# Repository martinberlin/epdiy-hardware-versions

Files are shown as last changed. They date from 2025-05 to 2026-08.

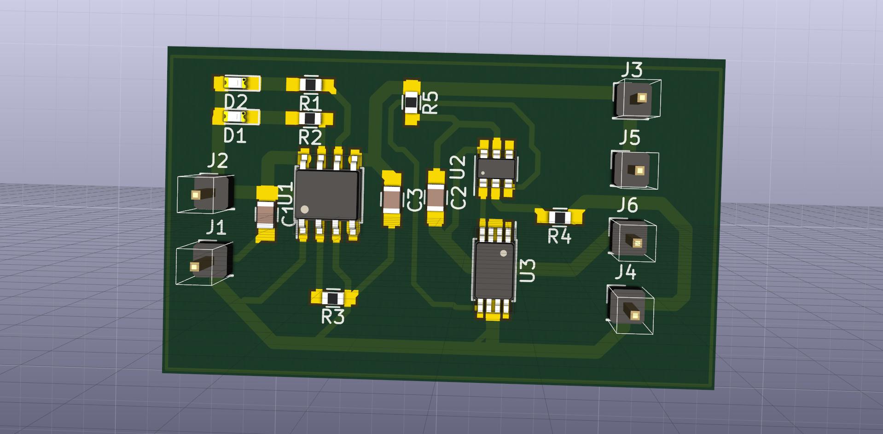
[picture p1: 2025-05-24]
versions/v7-raw-34/tp4056/out/charger_stepup2.jpg

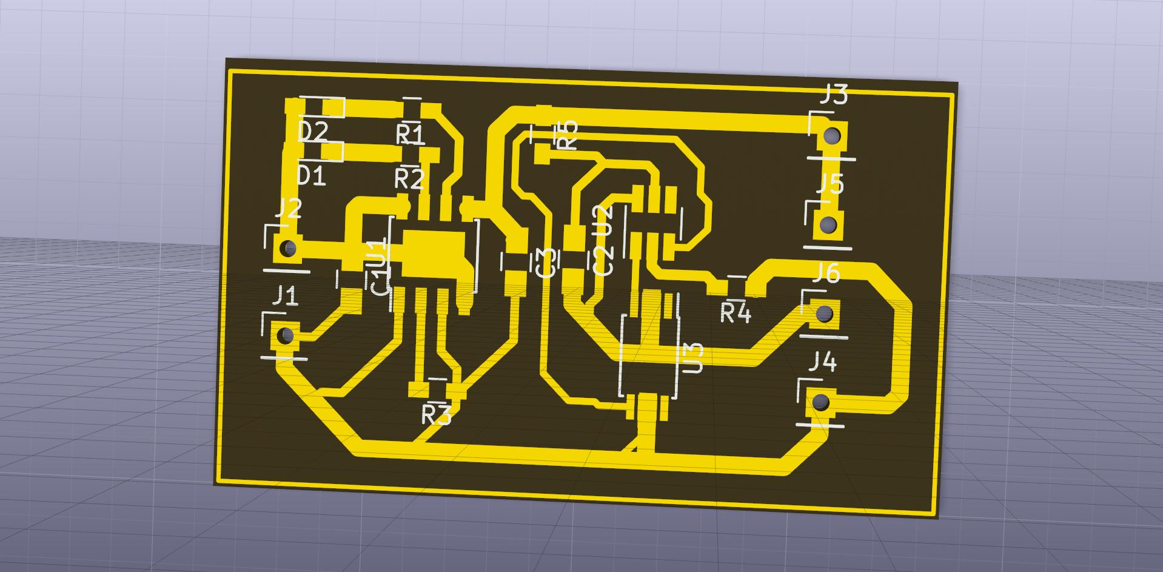
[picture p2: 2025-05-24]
versions/v7-raw-34/tp4056/out/charger_stepup1.jpg

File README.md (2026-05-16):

# EPDiy Hardware 

Design files for [EPDiy](https://github.com/vroland/epdiy) controllers, controller variants, display adaptors, and other related hardware.  
See [vroland.github.io/epdiy-hardware/](https://vroland.github.io/epdiy-hardware/) for available hardware.

## What is EPDiy?

Please refer to the [main project repository](https://github.com/vroland/epdiy) for more information.

## Cloning

Make sure to clone recursively, to get hardware library submodules:
```
git clone git@github.com:vroland/epdiy-hardware.git --recursive
# or with http
git clone https://github.com/vroland/epdiy-hardware.git --recursive
```

## Contributing Hardware

Contributions in the form of adapter boards, utilities or epdiy variants are always welcome!
Please submit a PR and make sure your KiCAD project is in the right format, so our automation can build 
the manufacturing files and overview page:

* For every board, the KiCAD project should be given a unique name, and have the same name as the containing folder. 
  Example: `epdiy-v7/epdiy-v7.{kicad_pro,kicad_pcb,kicad_sch}`. 
  An existing KiCAD project can be renamed by selecting `File -> Save As` in the main KiCAD window and saving it to a folder with the new name.
* Unless you *explicitly* specify otherwise, your contribution will be licensed under the Creative Commons Attribution-ShareAlike 4.0 International License.
  Feel free to mention in the README in your project folder how you want to be attributed.
  Please indicate in the PR if you intend to use a different license.
* Each board needs a README.md in it's project folder, which will also appear as description in the presentation page.
  Refer to `epdiy-v7/README.md` for an example.
* If it's a helper or an adapter board, place it in the appropriate `helpers` or `adapters` folder.
* Delete the manufacturing files and keep only the sources.
  Since we generate those automatically, having potentially outdated ones in the repo will be confusing. 
* Add your board to the `BOARDS` list in the root `Makefile`.
  This enables the continuous integration to build the manufacturing files for your board.

## Available Hardware

The full list of available hardware is available at [vroland.github.io/epdiy-hardware/](https://vroland.github.io/epdiy-hardware/).
For each board, we provide:

- Gerber files
- Bill of Materials (BoM)
- Pick & Place Positioning file
- PDF Schematic
- 3D model of the board for use in CAD

## Related repositories

- [Check FastJsonDL](https://github.com/martinberlin/FastJsonDL) a JSON domain language to draw GFX on displays that could be sent from a webservice or from an AI agent.
- [vroland/epdiy](https://github.com/vroland/epdiy)

## Licensing

Unless otherwise specified, the hardware sources provided are licensed under the terms of the Creative Commons Attribution-ShareAlike 4.0 International License.
<a rel="license" href="https://creativecommons.org/licenses/by-sa/4.0/">Creative Commons Attribution-ShareAlike 4.0 International License </a>

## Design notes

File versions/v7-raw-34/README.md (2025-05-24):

### Epdiy V7 RAW

The V7 controller iteration is based on the ESP32S3. Highlights of the new board include:

- Much faster updates thanks to the ESP32S3 SOC and the LCD peripheral
- Front light support for Kindle / Kaleido 
- LiPo charging

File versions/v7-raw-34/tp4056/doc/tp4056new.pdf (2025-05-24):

Модуль основан на чипе TP4056 (https://dlnmh9ip6v2uc.cloudfront.net/datasheets/Prototyping/TP4056.pdf) — контроллере зарядки Li-ion аккумуляторов со встроенным термодатчиком от NanJing Top Power ASIC Corp, это завершенное изделие с линейным зарядом по принципу постоянное напряжение/постоянный ток для одноэлементных литий-ионных аккумуляторов. Чип от компании из Нанкина, провинция Цзянсу, Китай. Специализация — системы питания игрушек, телефонов, LCD, LCM. Основана в 2003 году.
Контроллер выполнен в корпусе SOP-8, имет на нижней поверхности металлический теплосьемник не соединенный с контактами, позволяет заряжать аккумулятор током до 1000 ма (зависит от токозадающего резистора). Требует минимум навесных компонентов.
По сути это более навороченная модификация их же чипа TP4054, у которого в свою очередь куча аналогов (MCP73831, LTC4054, TB4054, TP4054, SGM4054, ACE4054, LP4054, U4054, BL4054, WPM4054, IT4504, Y1880, PT6102, PT6181, VS6102, HX6001, LC6000, LN5060, CX9058, EC49016, CYT5026, Q7051). Кто тут кому аналог, судить не берусь.

Расположение выводов:

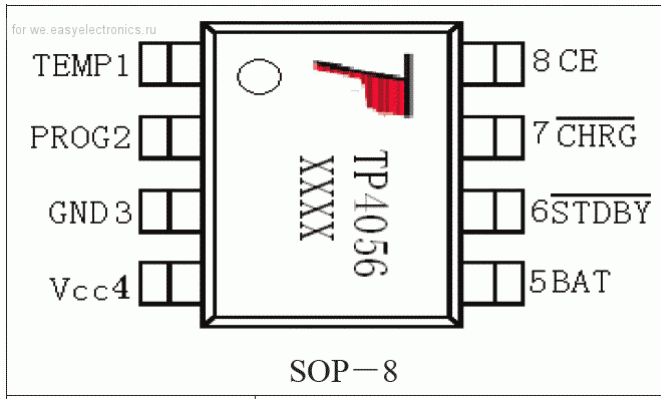
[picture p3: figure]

Описание выводов:
1. TEMP — подключение датчика температуры, встроенного в литий-ионную батарею. Если на выводе напряжение будет ниже 45% или выше 80% от напряжения питания, то зарядка приостановится. Контроль температуры отключается замыканием входа на общий провод.
2. PROG — Программирование тока зарядки (1.2к — 10к);
Постоянный ток зарядки и контроль напряжения зарядки выбираются сопротивлением резистора, между этим пином и GND;
Для всех режимов зарядки, зарядный ток может быть выведен из формулы:

3. GND — Общий;
4. Vcc — Напряжение питания, если ток потребления (ток зарядки батареи) становится ниже 30mA, контроллер уходит в спячку, потребляя от контакта BAT ~ 2mkA;
5. BAT — Подключение аккумуляторной батареи (ICR, IMR);
6. STDBY — Индикация окончания заряда (выход ОК, n-p-n), при слишком низком напряжении питания, или напряжении на входе ТЕМР не в диаппазоне — разомкнут; При подключенной батарее, в течении зарядки — разомкнут, по окончании — замкнут;
При неподключенной батарее замкнут;
7. CHRG — Индикация зарядки (выход ОК, n-p-n), при слишком низком напряжении питания, или напряжении на входе ТЕМР не в диаппазоне — разомкнут;
При подключенной батарее, в течении зарядки — замкнут, по окончании — разомкнут;
При неподключенной батарее, кратковременно включается с периодом 1-4 сек;
8. CE — Управление зарядкой. При подаче высокого уровня микросхема находится в рабочем режиме, при низком уровне контроллер в состоянии сна. Вход TTL и CMOS совместим;

Процесс зарядки состоит из нескольких этапов:
1. Контроль напряжения подключенного аккумулятора (постоянно);
2. Зарядка током 1/10 от запрограммированного резистором Rprog (100мА при Rprog = 1.2к) до уровня 2.9 В (если требуется);
3. Зарядка максимальным током (1000мА при Rprog = 1.2к);
4. При достижении на батарее 4.2 В идет стабилизация напряжения на уровне 4.2В. Ток падает по мере зарядки;
5. При достижении тока 1/10 от запрограммированного резистором Rprog (100мА при Rprog = 1.2к) зарядное устройство отключается. Переход к п. 1

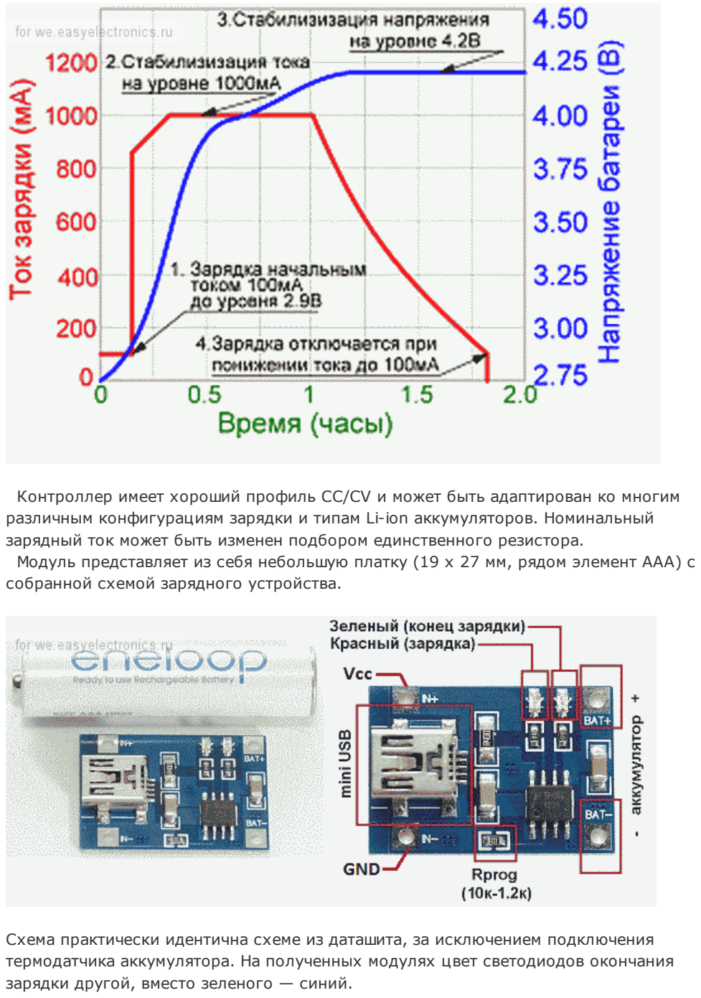
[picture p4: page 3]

Контроллер имеет хороший профиль CC/CV и может быть адаптирован ко многим различным конфигурациям зарядки и типам Li-ion аккумуляторов. Номинальный зарядный ток может быть изменен подбором единственного резистора.
Модуль представляет из себя небольшую платку (19 х 27 мм, рядом элемент ААА) с собранной схемой зарядного устройства.

Схема практически идентична схеме из даташита, за исключением подключения термодатчика аккумулятора. На полученных модулях цвет светодиодов окончания зарядки другой, вместо зеленого — синий.

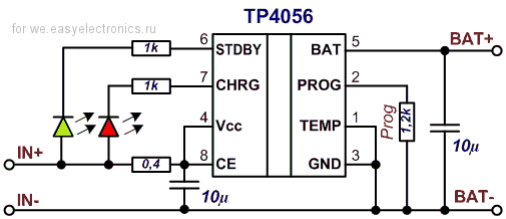
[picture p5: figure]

Можно (если понадобилось) вывести вход термодатчика отдельным проводком, напаявшись на лапку и отрезав ее от GND. Или же подняв лапку над платой и напаявшись. Если же хочется без паяния, надо просто заказать там же другой модуль:

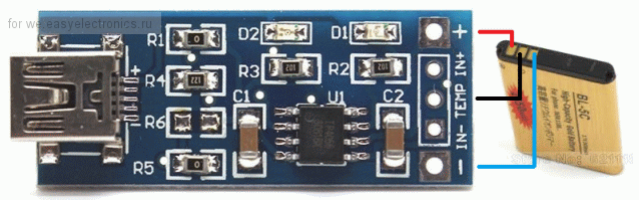
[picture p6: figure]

Отличие только в компоновке и габаритах (37x15мм).

Описание:
Напряжение питания +4,5...+8,0 вольт (более 5,5 В не рекомендуется, чип перегревается);
Разьем Mini-USB на плате, для питания от USB-порта компьютера или универсального блока питания;
Ток заряда 1,0 Ампер (1000 мА), легко программируется изменением значения резистора Rprog (от 1,2k до 10k (по даташиту, на самом деле до ~30k));
Важно: источник питания (USB порт, USB адаптер, или др.) должен обеспечивать ток заряда с некоторым запасом. Не все порты USB могут обеспечить ток более 500 мА; Напряжение окончания заряда аккумулятора: 4,2 вольта;
Светодиод индикации заряда;
Светодиод индикации окончания заряда;
Готовый модуль;
Миниатюрные размеры 19 х 27 мм;
Вес модуля 1,9 гр;

Тесты зарядки реальных аккумуляторов:

Заявленная емкость 3400mAh:

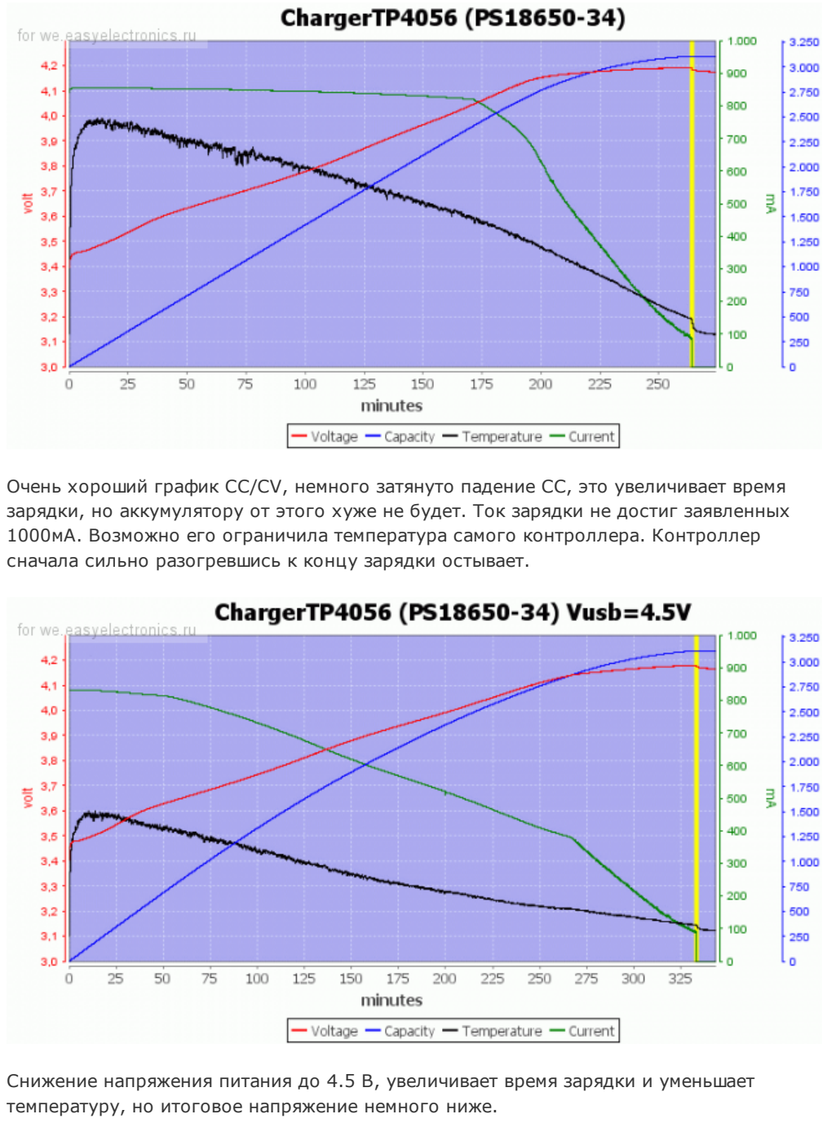
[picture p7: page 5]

Очень хороший график CC/CV, немного затянуто падение СС, это увеличивает время зарядки, но аккумулятору от этого хуже не будет. Ток зарядки не достиг заявленных 1000мА. Возможно его ограничила температура самого контроллера. Контроллер сначала сильно разогревшись к концу зарядки остывает.

Снижение напряжения питания до 4.5 В, увеличивает время зарядки и уменьшает температуру, но итоговое напряжение немного ниже.

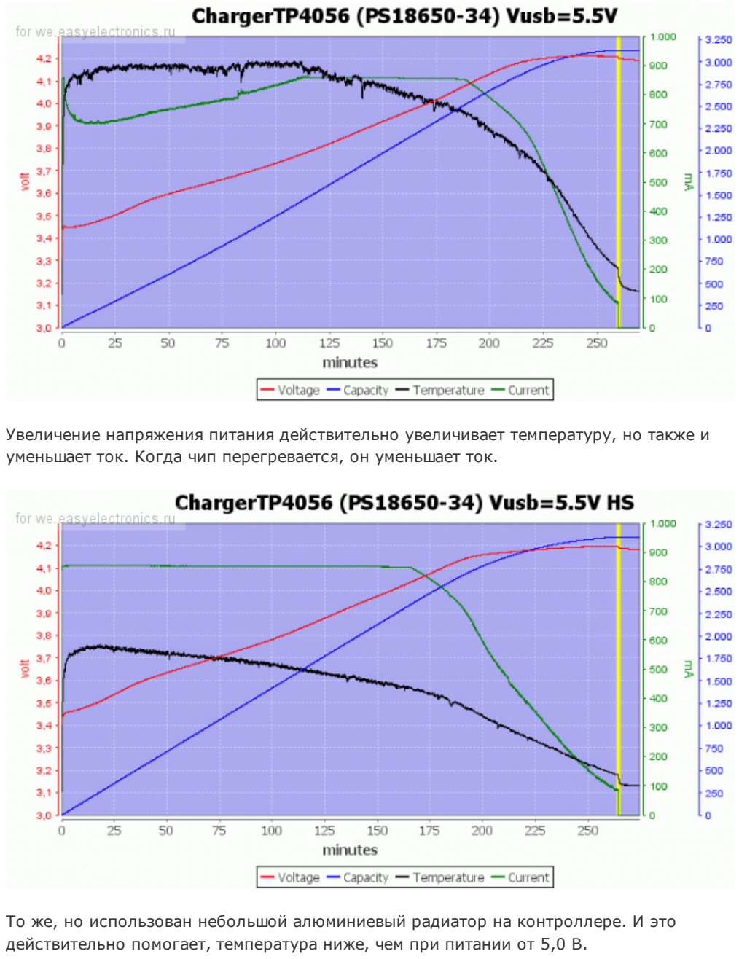
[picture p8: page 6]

Увеличение напряжения питания действительно увеличивает температуру, но также и уменьшает ток. Когда чип перегревается, он уменьшает ток.

То же, но использован небольшой алюминиевый радиатор на контроллере. И это действительно помогает, температура ниже, чем при питании от 5,0 В.

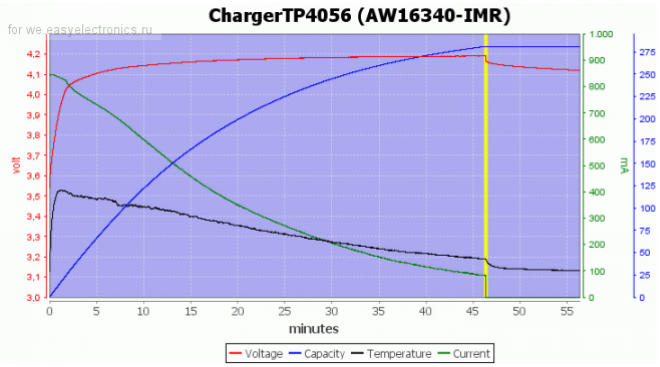
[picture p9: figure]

Старый 16340 IMR аккумулятор от видеокамеры также был заряжен успешно.

После окончания зарядки контроллер продолжает мониторинг напряжения аккумулятора. Ток, потребляемый схемой мониторинга 2-3 mkA. После падения напряжения до 4.0В, зарядка включается снова.
При отключении и подключении аккумулятора, зарядка включится только если напряжение аккумулятора ниже 4.0В.

Внимание!!! Контроллер имеет одну особенность, не описанную в даташите. Он не содержит схемы защиты от переполюсовки батареи. В этом случае контроллер гарантированно выходит из строя из-за превышения максимального тока и теплового пробоя. Но это только полбеды, контроллер пробивается накоротко, и на его выходе (батарее) появляется полное (!) входное напряжение.
Это особенно актуально для заряда пальчиковых аккумуляторов типа 18650. При установке очень легко ошибиться с полярностью.

Можно купить и модули с защитой:

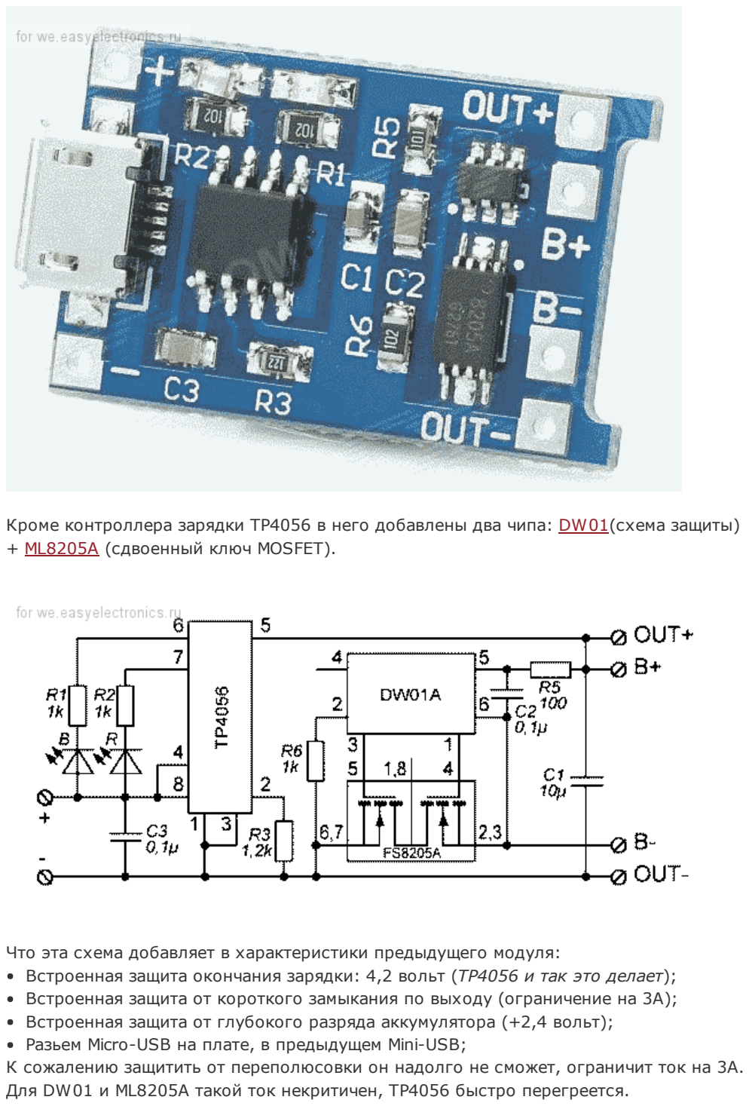
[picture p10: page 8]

Кроме контроллера зарядки ТP4056 в него добавлены два чипа: DW01(схема (https://cdn.sparkfun.com/assets/learn_tutorials/2/5/1/DW01-P_DataSheet_V10.pdf) защиты) + ML8205A (http://www.datasheet-pdf.com/datasheet-download.php?id=847699) (сдвоенный ключ MOSFET).

Что эта схема добавляет в характеристики предыдущего модуля:
Встроенная защита окончания зарядки: 4,2 вольт (ТP4056 и так это делает); Встроенная защита от короткого замыкания по выходу (ограничение на 3А); Встроенная защита от глубокого разряда аккумулятора (+2,4 вольт);
Разьем Micro-USB на плате, в предыдущем Mini-USB;
К сожалению защитить от переполюсовки он надолго не сможет, ограничит ток на 3А. Для DW01 и ML8205A такой ток некритичен, ТP4056 быстро перегреется.

Чего хотелось достичь?

Ранее я заказал и описАл простую платку (http://we.easyelectronics.ru/Shematech/platka-rasshireniya-tiny-rtc-i2c-modules.html) с DS1307Z и AT24C32 на борту.
Для резервного питания часов там заложен Li-ion аккумулятор LIR2032. Его подзарядка осуществляется постоянно, через резистор (1,8мкА), от питающего напряжения. Хотя упоминаний об этом в инете нет, меня убедили, что такая схема зарядки быстро убивает аккумулятор.
Данная зарядка бралась на замену резистору. Такая замена естественно дороже. Хотя если учесть цену данной платы (13,74 руб), плюсов будет больше.

Тестовая работа по подключению маломощного аккумулятора LIR2032 к зарядке на TP4056 была проведена здесь: (http://smokedprojects.blogspot.ru/2014/01/1-lithium-coin-cell-charger.html)

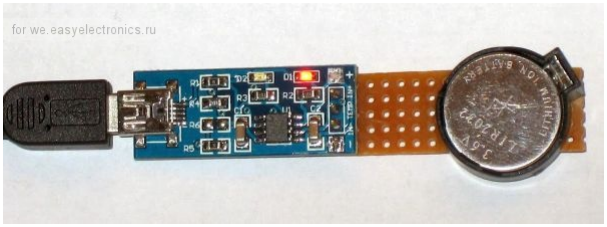
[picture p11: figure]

Автор изменил сопротивление токозадающего резистора с 1,2к на 33к, зарядный ток уменьшился до 45мА. По словам автора, зарядка разряженного аккумулятора занимает около часа.
Как это будет выглядеть в теории? Даташит на Li-MnO2
аккумуляторLIR2032 (http://www.astc.ru/data/delivery_list/content/eemb/pdf/LIR2032.pdf) рекомендует зарядку номинальным током 20мА и напряжением 4,2В. После падения тока до 4мА батарею можно считать полностью заряженной. Максимальный ток зарядки 35-45мА, в зависимости от производителя. Минимальное напряжение разряда аккумулятора до начала деградации ячейки 2,75В. Для аккумулятора гарантируется 500 циклов заряда/разряда с сохранением после них не менее 80% емкости.
В свою очередь контроллер Tp4056 не сможет обеспечить ток зарядки ниже 30мА, просто уйдет в сон. И ждать пока напряжение на аккумуляторе упадет до 2,75В тоже не будет, включит зарядку уже при падении до 4,0В. Таким образом он будет постоянно поддерживать аккумулятор на ~85-95% заряженным. Наверное это не оптимально для ячейки, но все же лучше, чем через резистор.

TP4056, (http://we.easyelectronics.ru/tag/TP4056/) Li-Ion (http://we.easyelectronics.ru/tag/Li-Ion/)

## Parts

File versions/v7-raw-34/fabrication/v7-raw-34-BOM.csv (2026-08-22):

Comment | Designator | Footprint | LCSC
4.7uF | C1,C4,C5,C7,C8,C11,C24,C26,C28,C31 | Capacitor_SMD:C_0805_2012Metric | C1779
1uF | C13,C14,C18 | Capacitor_SMD:C_0805_2012Metric | C28323
100nF | C15,C22,C23,C29,C30,C42 | Capacitor_SMD:C_0805_2012Metric | C49678
100uF | C17 | Capacitor_Tantalum_SMD:CP_EIA-3528-15_AVX-H | C16133
10uF | C2,C3,C9,C12,C16,C19,C32,C43 | Capacitor_SMD:C_0805_2012Metric | C15850
10nF | C20,C25 | Capacitor_SMD:C_0805_2012Metric | C1710
C_Polarized 100uF | C21 | Capacitor_Tantalum_SMD:CP_EIA-3528-21_Kemet-B | C129289
2.2uF | C27,C33 | Capacitor_SMD:C_0805_2012Metric | C49217
1uF/50V | C34,C36 | Capacitor_SMD:C_1206_3216Metric | C1848
1uF/25V | C35,C37,C38,C44 | Capacitor_SMD:C_0805_2012Metric | C28323
12 pF | C39,C40 | Capacitor_SMD:C_0603_1608Metric | C38523
22uF | C6,C10 | Capacitor_SMD:C_0805_2012Metric | C45783
MBR0540 | D1,D2,D3,D4,D5,D6,D7,D11 | Diode_SMD:D_SOD-123 | C21353
1N5817 | D10 | Diode_SMD:D_SOD-123 | C8598
1N4148WS | D12 | Diode_SMD:D_SOD-323 | C2128
LED GREEN | D8 | LED_SMD:LED_0805_2012Metric | C2297
LED RED | D9 | LED_SMD:LED_0805_2012Metric | C84256
USB_C_Receptacle_USB2.0 | J1,J4 | Connector_USB:USB_C_Receptacle_HRO_TYPE-C-31-M-12 | C165948
THD2528-11SD-GF | J11 | THD252811SDGF | C283232
S2B-PH-SM4-TB_LF__SN_ | J2 | footprint:S2BPHSM4TBLFSN | C295747
FH34SRJ-6S-0.5SH_99_ | J6 | footprint:C224194_6x1_FH34SRJ-6S-0.5SH50_HIR | C224194
4.7uH | L1 | Inductor_SMD:L_Taiyo-Yuden_NR-50xx_HandSoldering | C222947
2.2uH | L2 | Inductor_SMD:L_Taiyo-Yuden_NR-40xx_HandSoldering | C92959
22 uH | L3 | footprint:SWPA5040S282MT | C68434
AO3401A | Q1 | Package_TO_SOT_SMD:SOT-23 | C15127
MMBT3904 | Q3,Q4 | Package_TO_SOT_SMD:SOT-23 | C20526
10k | R1,R4,R6,R10,R11,R12,R14,R15 | Resistor_SMD:R_0603_1608Metric | C25804
25Ω | R13 | Resistor_SMD:R_0603_1608Metric | C308324
10 K | R17 | Resistor_SMD:R_0603_1608Metric | C25804
43k | R18 | Resistor_SMD:R_0603_1608Metric | C23172
1M | R19,R23 | Resistor_SMD:R_0603_1608Metric | C22935
5.1k | R2,R7 | Resistor_SMD:R_0603_1608Metric | C23186
52.3k | R20 | Resistor_SMD:R_0603_1608Metric | C23196
680k | R21 | Resistor_SMD:R_0603_1608Metric | C25822
150k | R22 | Resistor_SMD:R_0603_1608Metric | C22807
47.5k | R24 | Resistor_SMD:R_0603_1608Metric | C25819
47k | R26,R27,R28,R29 | Resistor_SMD:R_0603_1608Metric | C25819
2.4k | R3,R8 | Resistor_SMD:R_0603_1608Metric | C22940
100k | R30,R31 | Resistor_SMD:R_0603_1608Metric | C25803
0R | R5,R16 | Resistor_SMD:R_0603_1608Metric | C21189
3.8k | R9 | Resistor_SMD:R_0603_1608Metric | C103591
R_Pack04 | RN1 | footprint:RESN_F392JTCE_UNR_SD-pullup | C425297
10k/3380K | TH1 | Resistor_SMD:R_0603_1608Metric | C76589
RT9080-33GJ5 | U1 | Package_TO_SOT_SMD:TSOT-23-5 | C841192
ED060XC5 | U10 | epaper-breakout:X05A20H34G | C528053
TP4056 | U11 | epaper-breakout:TP4056_SOP-8-PP | C16581
PCF8563T | U2 | Package_SO:SOIC-8_3.9x4.9mm_P1.27mm | C7440
TPS651851RSLR | U3 | footprint:TPS651851RSLR | C139292
USBLC6-2P6 | U4 | Package_TO_SOT_SMD:SOT-666 | C2827693
XC6206PxxxMR | U5 | Package_TO_SOT_SMD:SOT-23-3 | C5446
RY3730 | U6 | footprint:SOT-23-6_RY3730_Led_PWM | C370887
ESP32-S3-WROOM-1 | U8 | Espressif:ESP32-S3-WROOM-1 | C2913202
CH340C | U9 | Package_SO:SOIC-16_3.9x9.9mm_P1.27mm | C84681
Crystal_Small | Y1 | footprint:Q13FC1350000400-Crystal | C32346
SM04B-SRSS-TB_LFSN_ | J12 | QWIIC_SM04B-SRSS-TB_LFSN_ | C160404

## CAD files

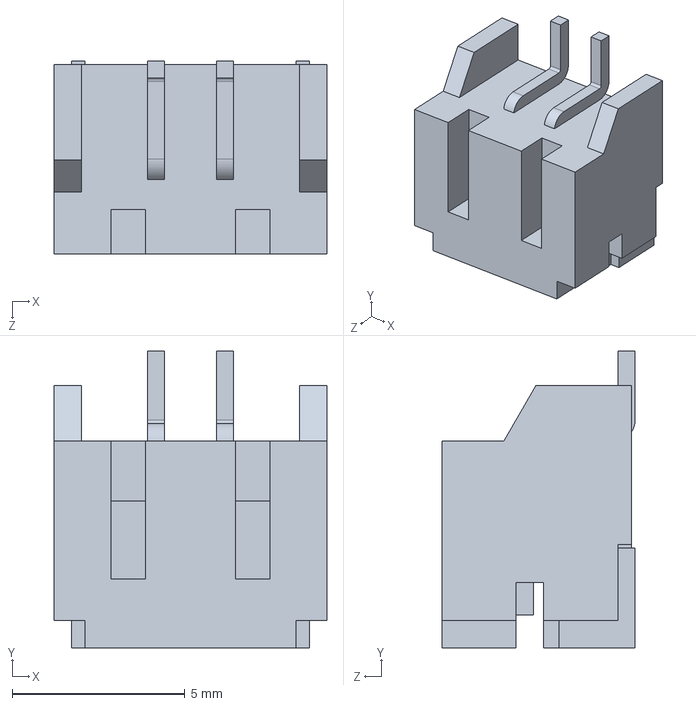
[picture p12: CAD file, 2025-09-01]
versions/v7-raw-34/3dmodels/S2B-PH-SM4-TB_LF__SN_.stp
7.90 x 8.60 x 5.60 mm

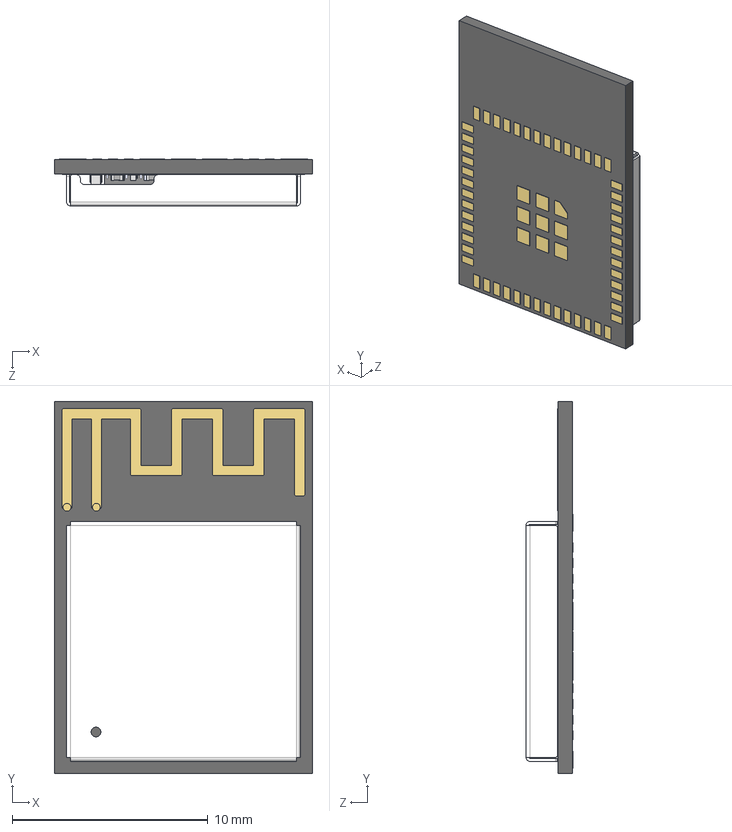
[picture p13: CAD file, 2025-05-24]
versions/v7-raw-34/kicad-libraries/3d/ESP32-MINI-1.STEP
13.2 x 19.0 x 2.40 mm
DFN1006.STEP^DFN1006.STEP_Submodel-SOD882_part_DesignRootModel_PCB_ESP32-MINI-1_V1(2)_PCB_ESP32-MINI-1_V1
trace_1^Submodel-MINI-ANT-TYPED_2110587435_part_DesignRootModel_PCB_ESP32-MINI-1_V1(2)_PCB_ESP32-MINI-1_V1
C0402_20210301.STEP^C0402_20210301.STEP_Submodel-C0402_part_DesignRootModel_PCB_ESP32-MINI-1_V1(2)_PCB_ESP32-MINI-1_V1
R0201_20210301.STEP^R0201_20210301.STEP_Submodel-R0201_part_DesignRootModel_PCB_ESP32-MINI-1_V1(2)_PCB_ESP32-MINI-1_V1 x 3
C0201_20210301.STEP^C0201_20210301.STEP_Submodel-C0201_part_DesignRootModel_PCB_ESP32-MINI-1_V1(2)_PCB_ESP32-MINI-1_V1 x 15
L0201_20210301.STEP^L0201_20210301.STEP_Submodel-L0201_part_DesignRootModel_PCB_ESP32-MINI-1_V1(2)_PCB_ESP32-MINI-1_V1 x 2
XTAL3225_20210301.STEP^XTAL3225_20210301.STEP_Submodel-XTAL3225_part_DesignRootModel_PCB_ESP32-MINI-1_V1(2)_PCB_ESP32-MINI-1_V1
ESP32_5x5_20210301.STEP^ESP32_5x5_20210301.STEP_Submodel-QFN48EB_0P35_5_part_DesignRootModel_PCB_ESP32-MINI-1_V1(2)_PCB_ESP32-MINI-1_V1
uid__4^DesignRootModel_PCB_ESP32-MINI-1_V1(2)_PCB_ESP32-MINI-1_V1
uid__4-1^DesignRootModel_PCB_ESP32-MINI-1_V1(2)_PCB_ESP32-MINI-1_V1
uid__4-2^DesignRootModel_PCB_ESP32-MINI-1_V1(2)_PCB_ESP32-MINI-1_V1
uid__4-3^DesignRootModel_PCB_ESP32-MINI-1_V1(2)_PCB_ESP32-MINI-1_V1
uid__4-4^DesignRootModel_PCB_ESP32-MINI-1_V1(2)_PCB_ESP32-MINI-1_V1
uid__4-5^DesignRootModel_PCB_ESP32-MINI-1_V1(2)_PCB_ESP32-MINI-1_V1
uid__4-6^DesignRootModel_PCB_ESP32-MINI-1_V1(2)_PCB_ESP32-MINI-1_V1
uid__4-7^DesignRootModel_PCB_ESP32-MINI-1_V1(2)_PCB_ESP32-MINI-1_V1
uid__4-8^DesignRootModel_PCB_ESP32-MINI-1_V1(2)_PCB_ESP32-MINI-1_V1
uid__4-9^DesignRootModel_PCB_ESP32-MINI-1_V1(2)_PCB_ESP32-MINI-1_V1
uid__4-10^DesignRootModel_PCB_ESP32-MINI-1_V1(2)_PCB_ESP32-MINI-1_V1
uid__4-11^DesignRootModel_PCB_ESP32-MINI-1_V1(2)_PCB_ESP32-MINI-1_V1
uid__4-12^DesignRootModel_PCB_ESP32-MINI-1_V1(2)_PCB_ESP32-MINI-1_V1
uid__4-18^DesignRootModel_PCB_ESP32-MINI-1_V1(2)_PCB_ESP32-MINI-1_V1
uid__4-19^DesignRootModel_PCB_ESP32-MINI-1_V1(2)_PCB_ESP32-MINI-1_V1
uid__4-31^DesignRootModel_PCB_ESP32-MINI-1_V1(2)_PCB_ESP32-MINI-1_V1
uid__4-32^DesignRootModel_PCB_ESP32-MINI-1_V1(2)_PCB_ESP32-MINI-1_V1
uid__4-44^DesignRootModel_PCB_ESP32-MINI-1_V1(2)_PCB_ESP32-MINI-1_V1
uid__4-45^DesignRootModel_PCB_ESP32-MINI-1_V1(2)_PCB_ESP32-MINI-1_V1
uid__4-55^DesignRootModel_PCB_ESP32-MINI-1_V1(2)_PCB_ESP32-MINI-1_V1
uid__4-56^DesignRootModel_PCB_ESP32-MINI-1_V1(2)_PCB_ESP32-MINI-1_V1
uid__4-61^DesignRootModel_PCB_ESP32-MINI-1_V1(2)_PCB_ESP32-MINI-1_V1
uid__4-62^DesignRootModel_PCB_ESP32-MINI-1_V1(2)_PCB_ESP32-MINI-1_V1
uid__4-63^DesignRootModel_PCB_ESP32-MINI-1_V1(2)_PCB_ESP32-MINI-1_V1
uid__4-64^DesignRootModel_PCB_ESP32-MINI-1_V1(2)_PCB_ESP32-MINI-1_V1
uid__4-65^DesignRootModel_PCB_ESP32-MINI-1_V1(2)_PCB_ESP32-MINI-1_V1
uid__4-69^DesignRootModel_PCB_ESP32-MINI-1_V1(2)_PCB_ESP32-MINI-1_V1
uid__4-70^DesignRootModel_PCB_ESP32-MINI-1_V1(2)_PCB_ESP32-MINI-1_V1
uid__4-80^DesignRootModel_PCB_ESP32-MINI-1_V1(2)_PCB_ESP32-MINI-1_V1
uid__4-81^DesignRootModel_PCB_ESP32-MINI-1_V1(2)_PCB_ESP32-MINI-1_V1
uid__4-82^DesignRootModel_PCB_ESP32-MINI-1_V1(2)_PCB_ESP32-MINI-1_V1
uid__4-83^DesignRootModel_PCB_ESP32-MINI-1_V1(2)_PCB_ESP32-MINI-1_V1
uid__4-84^DesignRootModel_PCB_ESP32-MINI-1_V1(2)_PCB_ESP32-MINI-1_V1
uid__4-87^DesignRootModel_PCB_ESP32-MINI-1_V1(2)_PCB_ESP32-MINI-1_V1
uid__4-88^DesignRootModel_PCB_ESP32-MINI-1_V1(2)_PCB_ESP32-MINI-1_V1
uid__4-101^DesignRootModel_PCB_ESP32-MINI-1_V1(2)_PCB_ESP32-MINI-1_V1
uid__4-102^DesignRootModel_PCB_ESP32-MINI-1_V1(2)_PCB_ESP32-MINI-1_V1
uid__4-104^DesignRootModel_PCB_ESP32-MINI-1_V1(2)_PCB_ESP32-MINI-1_V1
uid__4-105^DesignRootModel_PCB_ESP32-MINI-1_V1(2)_PCB_ESP32-MINI-1_V1
uid__4-106^DesignRootModel_PCB_ESP32-MINI-1_V1(2)_PCB_ESP32-MINI-1_V1
uid__4-109^DesignRootModel_PCB_ESP32-MINI-1_V1(2)_PCB_ESP32-MINI-1_V1
uid__4-110^DesignRootModel_PCB_ESP32-MINI-1_V1(2)_PCB_ESP32-MINI-1_V1
uid__4-120^DesignRootModel_PCB_ESP32-MINI-1_V1(2)_PCB_ESP32-MINI-1_V1
uid__4-121^DesignRootModel_PCB_ESP32-MINI-1_V1(2)_PCB_ESP32-MINI-1_V1
uid__4-129^DesignRootModel_PCB_ESP32-MINI-1_V1(2)_PCB_ESP32-MINI-1_V1
uid__4-130^DesignRootModel_PCB_ESP32-MINI-1_V1(2)_PCB_ESP32-MINI-1_V1
uid__4-139^DesignRootModel_PCB_ESP32-MINI-1_V1(2)_PCB_ESP32-MINI-1_V1
uid__4-140^DesignRootModel_PCB_ESP32-MINI-1_V1(2)_PCB_ESP32-MINI-1_V1
uid__4-155^DesignRootModel_PCB_ESP32-MINI-1_V1(2)_PCB_ESP32-MINI-1_V1
uid__4-157^DesignRootModel_PCB_ESP32-MINI-1_V1(2)_PCB_ESP32-MINI-1_V1
uid__4-158^DesignRootModel_PCB_ESP32-MINI-1_V1(2)_PCB_ESP32-MINI-1_V1
uid__4-159^DesignRootModel_PCB_ESP32-MINI-1_V1(2)_PCB_ESP32-MINI-1_V1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

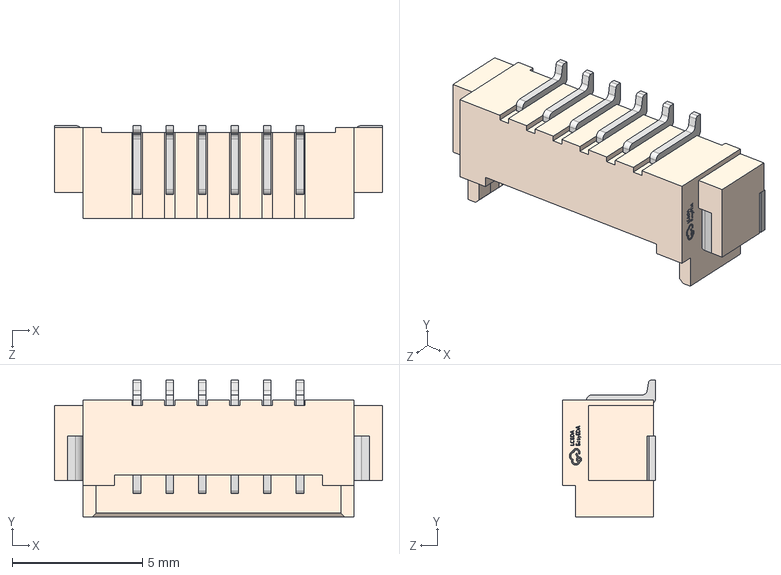
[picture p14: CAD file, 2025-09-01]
versions/v7-raw-34/3dmodels/CONN-SMD_6P-P1.25_HC-1.25-6PWT.step
12.6 x 5.25 x 3.57 mm

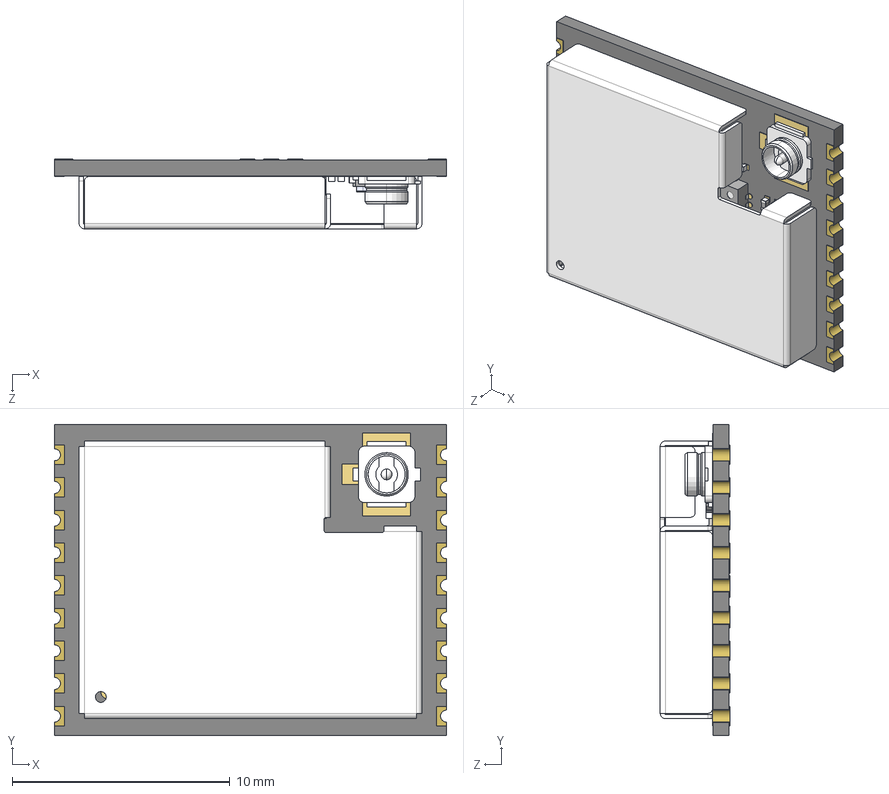
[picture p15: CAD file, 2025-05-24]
versions/v7-raw-34/kicad-libraries/3d/ESP32-C3-WROOM-02U.STEP
18.0 x 14.3 x 3.20 mm
ESP32-C3_20210301^ESP32-C3_20210301____PCB_ESP32-C3-WROOM-02U_ZZZZ.STEP_ESP32-C3-WROOM-02U_20210906(2)_ESP32-C3-WROOM-02U_20210906.STEP
DFN1006^DFN1006_____ (2) ___PCB_ESP32-C3-WROOM-02U_ZZZZ.STEP_ESP32-C3-WROOM-02U_20210906(2)_ESP32-C3-WROOM-02U_20210906.STEP
R0201_20210301^R0201_20210301_____ (3) ___PCB_ESP32-C3-WROOM-02U_ZZZZ.STEP_ESP32-C3-WROOM-02U_20210906(2)_ESP32-C3-WROOM-02U_20210906.STEP
R0201_20210301^R0201_20210301_____ (4) ___PCB_ESP32-C3-WROOM-02U_ZZZZ.STEP_ESP32-C3-WROOM-02U_20210906(2)_ESP32-C3-WROOM-02U_20210906.STEP
R0201_20210301^R0201_20210301_____ (5) ___PCB_ESP32-C3-WROOM-02U_ZZZZ.STEP_ESP32-C3-WROOM-02U_20210906(2)_ESP32-C3-WROOM-02U_20210906.STEP
R0201_20210301^R0201_20210301_____ (6) ___PCB_ESP32-C3-WROOM-02U_ZZZZ.STEP_ESP32-C3-WROOM-02U_20210906(2)_ESP32-C3-WROOM-02U_20210906.STEP
R0201_20210301^R0201_20210301_____ (7) ___PCB_ESP32-C3-WROOM-02U_ZZZZ.STEP_ESP32-C3-WROOM-02U_20210906(2)_ESP32-C3-WROOM-02U_20210906.STEP
R0201_20210301^R0201_20210301_____ (8) ___PCB_ESP32-C3-WROOM-02U_ZZZZ.STEP_ESP32-C3-WROOM-02U_20210906(2)_ESP32-C3-WROOM-02U_20210906.STEP
R0201_20210301^R0201_20210301_____ (9) ___PCB_ESP32-C3-WROOM-02U_ZZZZ.STEP_ESP32-C3-WROOM-02U_20210906(2)_ESP32-C3-WROOM-02U_20210906.STEP
R0201_20210301^R0201_20210301_____ (10) ___PCB_ESP32-C3-WROOM-02U_ZZZZ.STEP_ESP32-C3-WROOM-02U_20210906(2)_ESP32-C3-WROOM-02U_20210906.STEP
L0201_20210301^L0201_20210301_____ (11) ___PCB_ESP32-C3-WROOM-02U_ZZZZ.STEP_ESP32-C3-WROOM-02U_20210906(2)_ESP32-C3-WROOM-02U_20210906.STEP
L0201_20210301^L0201_20210301_____ (12) ___PCB_ESP32-C3-WROOM-02U_ZZZZ.STEP_ESP32-C3-WROOM-02U_20210906(2)_ESP32-C3-WROOM-02U_20210906.STEP
C0402_20210301^C0402_20210301_____ (13) ___PCB_ESP32-C3-WROOM-02U_ZZZZ.STEP_ESP32-C3-WROOM-02U_20210906(2)_ESP32-C3-WROOM-02U_20210906.STEP
C0201_20210301^C0201_20210301_____ (14) ___PCB_ESP32-C3-WROOM-02U_ZZZZ.STEP_ESP32-C3-WROOM-02U_20210906(2)_ESP32-C3-WROOM-02U_20210906.STEP
C0201_20210301^C0201_20210301_____ (15) ___PCB_ESP32-C3-WROOM-02U_ZZZZ.STEP_ESP32-C3-WROOM-02U_20210906(2)_ESP32-C3-WROOM-02U_20210906.STEP
C0201_20210301^C0201_20210301_____ (16) ___PCB_ESP32-C3-WROOM-02U_ZZZZ.STEP_ESP32-C3-WROOM-02U_20210906(2)_ESP32-C3-WROOM-02U_20210906.STEP
C0201_20210301^C0201_20210301_____ (17) ___PCB_ESP32-C3-WROOM-02U_ZZZZ.STEP_ESP32-C3-WROOM-02U_20210906(2)_ESP32-C3-WROOM-02U_20210906.STEP
C0201_20210301^C0201_20210301_____ (18) ___PCB_ESP32-C3-WROOM-02U_ZZZZ.STEP_ESP32-C3-WROOM-02U_20210906(2)_ESP32-C3-WROOM-02U_20210906.STEP
C0201_20210301^C0201_20210301_____ (19) ___PCB_ESP32-C3-WROOM-02U_ZZZZ.STEP_ESP32-C3-WROOM-02U_20210906(2)_ESP32-C3-WROOM-02U_20210906.STEP
C0201_20210301^C0201_20210301_____ (20) ___PCB_ESP32-C3-WROOM-02U_ZZZZ.STEP_ESP32-C3-WROOM-02U_20210906(2)_ESP32-C3-WROOM-02U_20210906.STEP
C0201_20210301^C0201_20210301_____ (21) ___PCB_ESP32-C3-WROOM-02U_ZZZZ.STEP_ESP32-C3-WROOM-02U_20210906(2)_ESP32-C3-WROOM-02U_20210906.STEP
C0201_20210301^C0201_20210301_____ (22) ___PCB_ESP32-C3-WROOM-02U_ZZZZ.STEP_ESP32-C3-WROOM-02U_20210906(2)_ESP32-C3-WROOM-02U_20210906.STEP
C0201_20210301^C0201_20210301_____ (23) ___PCB_ESP32-C3-WROOM-02U_ZZZZ.STEP_ESP32-C3-WROOM-02U_20210906(2)_ESP32-C3-WROOM-02U_20210906.STEP
C0201_20210301^C0201_20210301_____ (24) ___PCB_ESP32-C3-WROOM-02U_ZZZZ.STEP_ESP32-C3-WROOM-02U_20210906(2)_ESP32-C3-WROOM-02U_20210906.STEP
XTAL3225_20210301^XTAL3225_20210301_____ (25) ___PCB_ESP32-C3-WROOM-02U_ZZZZ.STEP_ESP32-C3-WROOM-02U_20210906(2)_ESP32-C3-WROOM-02U_20210906.STEP
SOIC8_208_20210301^SOIC8_208_20210301_____ (26) ___PCB_ESP32-C3-WROOM-02U_ZZZZ.STEP_ESP32-C3-WROOM-02U_20210906(2)_ESP32-C3-WROOM-02U_20210906.STEP
^__PCB_ESP32-C3-WROOM-02U_ZZZZ.STEP_ESP32-C3-WROOM-02U_20210906(2)_ESP32-C3-WROOM-02U_20210906-0.STEP
____ (2) ^__PCB_ESP32-C3-WROOM-02U_ZZZZ.STEP_ESP32-C3-WROOM-02U_20210906(2)_ESP32-C3-WROOM-02U_20210906-1.STEP
____ (3) ^__PCB_ESP32-C3-WROOM-02U_ZZZZ.STEP_ESP32-C3-WROOM-02U_20210906(2)_ESP32-C3-WROOM-02U_20210906-2.STEP
____ (4) ^__PCB_ESP32-C3-WROOM-02U_ZZZZ.STEP_ESP32-C3-WROOM-02U_20210906(2)_ESP32-C3-WROOM-02U_20210906-3.STEP
____ (5) ^__PCB_ESP32-C3-WROOM-02U_ZZZZ.STEP_ESP32-C3-WROOM-02U_20210906(2)_ESP32-C3-WROOM-02U_20210906-4.STEP
____ (6) ^__PCB_ESP32-C3-WROOM-02U_ZZZZ.STEP_ESP32-C3-WROOM-02U_20210906(2)_ESP32-C3-WROOM-02U_20210906-5.STEP
____ (7) ^__PCB_ESP32-C3-WROOM-02U_ZZZZ.STEP_ESP32-C3-WROOM-02U_20210906(2)_ESP32-C3-WROOM-02U_20210906-6.STEP
____ (8) ^__PCB_ESP32-C3-WROOM-02U_ZZZZ.STEP_ESP32-C3-WROOM-02U_20210906(2)_ESP32-C3-WROOM-02U_20210906-7.STEP
____ (9) ^__PCB_ESP32-C3-WROOM-02U_ZZZZ.STEP_ESP32-C3-WROOM-02U_20210906(2)_ESP32-C3-WROOM-02U_20210906-8.STEP
____ (10) ^__PCB_ESP32-C3-WROOM-02U_ZZZZ.STEP_ESP32-C3-WROOM-02U_20210906(2)_ESP32-C3-WROOM-02U_20210906-9.STEP
____ (11) ^__PCB_ESP32-C3-WROOM-02U_ZZZZ.STEP_ESP32-C3-WROOM-02U_20210906(2)_ESP32-C3-WROOM-02U_20210906-10.STEP
____ (12) ^__PCB_ESP32-C3-WROOM-02U_ZZZZ.STEP_ESP32-C3-WROOM-02U_20210906(2)_ESP32-C3-WROOM-02U_20210906-11.STEP
____ (13) ^__PCB_ESP32-C3-WROOM-02U_ZZZZ.STEP_ESP32-C3-WROOM-02U_20210906(2)_ESP32-C3-WROOM-02U_20210906-12.STEP
____ (14) ^__PCB_ESP32-C3-WROOM-02U_ZZZZ.STEP_ESP32-C3-WROOM-02U_20210906(2)_ESP32-C3-WROOM-02U_20210906-13.STEP
____ (15) ^__PCB_ESP32-C3-WROOM-02U_ZZZZ.STEP_ESP32-C3-WROOM-02U_20210906(2)_ESP32-C3-WROOM-02U_20210906-14.STEP
____ (16) ^__PCB_ESP32-C3-WROOM-02U_ZZZZ.STEP_ESP32-C3-WROOM-02U_20210906(2)_ESP32-C3-WROOM-02U_20210906-15.STEP
____ (17) ^__PCB_ESP32-C3-WROOM-02U_ZZZZ.STEP_ESP32-C3-WROOM-02U_20210906(2)_ESP32-C3-WROOM-02U_20210906-16.STEP
____ (18) ^__PCB_ESP32-C3-WROOM-02U_ZZZZ.STEP_ESP32-C3-WROOM-02U_20210906(2)_ESP32-C3-WROOM-02U_20210906-17.STEP
____ (19) ^__PCB_ESP32-C3-WROOM-02U_ZZZZ.STEP_ESP32-C3-WROOM-02U_20210906(2)_ESP32-C3-WROOM-02U_20210906-18.STEP
____ (20) ^__PCB_ESP32-C3-WROOM-02U_ZZZZ.STEP_ESP32-C3-WROOM-02U_20210906(2)_ESP32-C3-WROOM-02U_20210906-19.STEP
____ (21) ^__PCB_ESP32-C3-WROOM-02U_ZZZZ.STEP_ESP32-C3-WROOM-02U_20210906(2)_ESP32-C3-WROOM-02U_20210906-20.STEP
____ (22) ^__PCB_ESP32-C3-WROOM-02U_ZZZZ.STEP_ESP32-C3-WROOM-02U_20210906(2)_ESP32-C3-WROOM-02U_20210906-21.STEP
____ (23) ^__PCB_ESP32-C3-WROOM-02U_ZZZZ.STEP_ESP32-C3-WROOM-02U_20210906(2)_ESP32-C3-WROOM-02U_20210906-22.STEP
____ (24) ^__PCB_ESP32-C3-WROOM-02U_ZZZZ.STEP_ESP32-C3-WROOM-02U_20210906(2)_ESP32-C3-WROOM-02U_20210906-23.STEP
____ (25) ^__PCB_ESP32-C3-WROOM-02U_ZZZZ.STEP_ESP32-C3-WROOM-02U_20210906(2)_ESP32-C3-WROOM-02U_20210906-24.STEP
____ (26) ^__PCB_ESP32-C3-WROOM-02U_ZZZZ.STEP_ESP32-C3-WROOM-02U_20210906(2)_ESP32-C3-WROOM-02U_20210906-25.STEP
____ (27) ^__PCB_ESP32-C3-WROOM-02U_ZZZZ.STEP_ESP32-C3-WROOM-02U_20210906(2)_ESP32-C3-WROOM-02U_20210906.STEP
____ (28) ^__PCB_ESP32-C3-WROOM-02U_ZZZZ.STEP_ESP32-C3-WROOM-02U_20210906(2)_ESP32-C3-WROOM-02U_20210906.STEP
____ (29) ^__PCB_ESP32-C3-WROOM-02U_ZZZZ.STEP_ESP32-C3-WROOM-02U_20210906(2)_ESP32-C3-WROOM-02U_20210906.STEP
____ (30) ^__PCB_ESP32-C3-WROOM-02U_ZZZZ.STEP_ESP32-C3-WROOM-02U_20210906(2)_ESP32-C3-WROOM-02U_20210906.STEP
____ (31) ^__PCB_ESP32-C3-WROOM-02U_ZZZZ.STEP_ESP32-C3-WROOM-02U_20210906(2)_ESP32-C3-WROOM-02U_20210906.STEP
____ (32) ^__PCB_ESP32-C3-WROOM-02U_ZZZZ.STEP_ESP32-C3-WROOM-02U_20210906(2)_ESP32-C3-WROOM-02U_20210906.STEP
____ (33) ^__PCB_ESP32-C3-WROOM-02U_ZZZZ.STEP_ESP32-C3-WROOM-02U_20210906(2)_ESP32-C3-WROOM-02U_20210906.STEP
____ (34) ^__PCB_ESP32-C3-WROOM-02U_ZZZZ.STEP_ESP32-C3-WROOM-02U_20210906(2)_ESP32-C3-WROOM-02U_20210906.STEP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

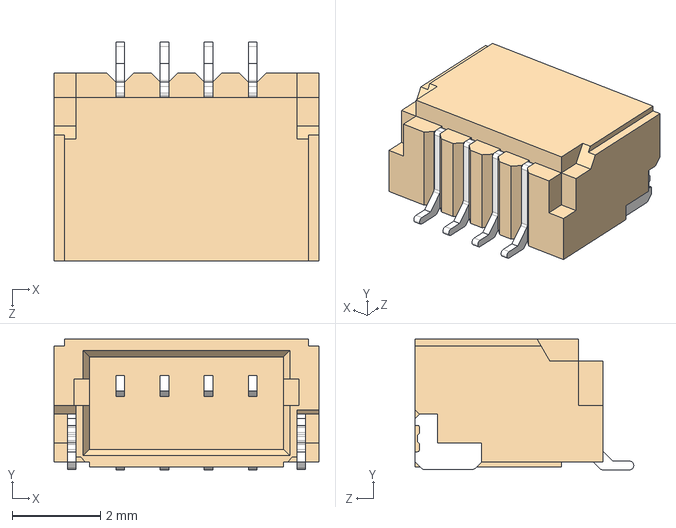
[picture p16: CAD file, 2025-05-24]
versions/v7-raw-34/3dmodels/QWIIC_SM04B-SRSS-TB_LF__SN_.stp
6.00 x 2.96 x 4.95 mm

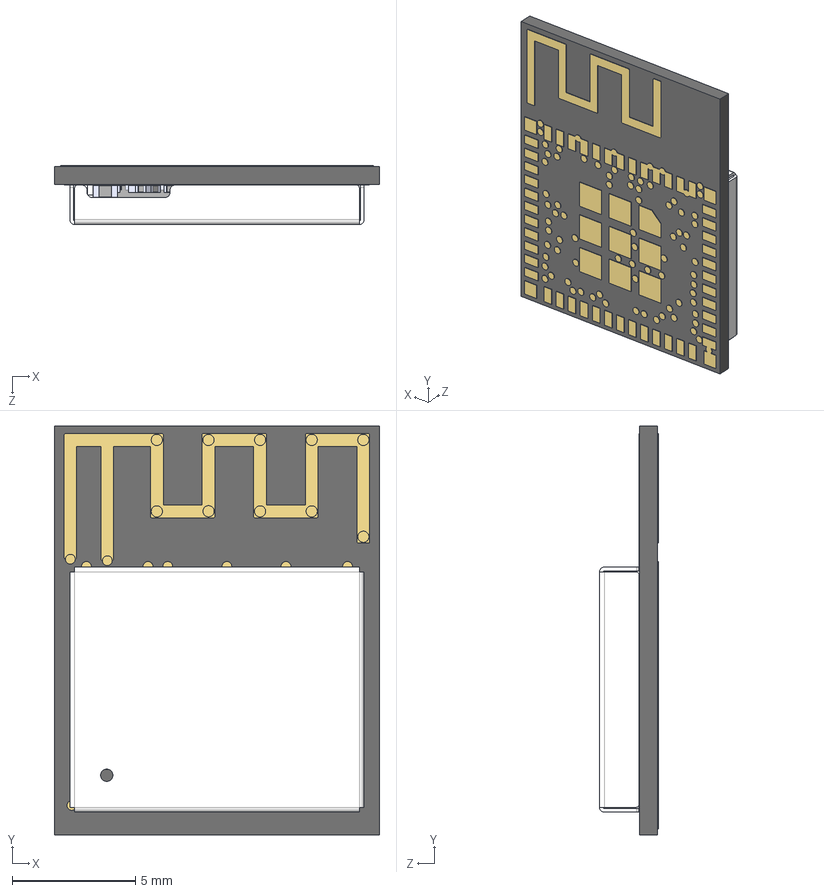
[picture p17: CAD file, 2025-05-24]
versions/v7-raw-34/kicad-libraries/3d/ESP32-C3-MINI-1.STEP
13.2 x 16.6 x 2.40 mm
DFN1006.STEP^DFN1006.STEP_Submodel-SOD882_part_DesignRootModel_PCB_ESP32-C3-MINI-1_V1(2)_PCB_ESP32-C3-MINI-1_V1
R0201_20210301.STEP^R0201_20210301.STEP_Submodel-R0201_part_DesignRootModel_PCB_ESP32-C3-MINI-1_V1(2)_PCB_ESP32-C3-MINI-1_V1 x 3
placementOutline^Submodel-noModelForPart_MINI-ANT-TYPED-H_1968823293_Submodel-MINI-ANT-TYPED-H_1968823293_part_DesignRootModel_PCB_ESP32-C3-MINI-1_V1(2)_PCB_ESP
placementOutline-0^Submodel-noModelForPart_MINI-ANT-TYPED-H_1968823293_Submodel-MINI-ANT-TYPED-H_1968823293_part_DesignRootModel_PCB_ESP32-C3-MINI-1_V1(2)_PCB_E
placementOutline-1^Submodel-noModelForPart_MINI-ANT-TYPED-H_1968823293_Submodel-MINI-ANT-TYPED-H_1968823293_part_DesignRootModel_PCB_ESP32-C3-MINI-1_V1(2)_PCB_E
placementOutline-2^Submodel-noModelForPart_MINI-ANT-TYPED-H_1968823293_Submodel-MINI-ANT-TYPED-H_1968823293_part_DesignRootModel_PCB_ESP32-C3-MINI-1_V1(2)_PCB_E
placementOutline-3^Submodel-noModelForPart_MINI-ANT-TYPED-H_1968823293_Submodel-MINI-ANT-TYPED-H_1968823293_part_DesignRootModel_PCB_ESP32-C3-MINI-1_V1(2)_PCB_E
placementOutline-4^Submodel-noModelForPart_MINI-ANT-TYPED-H_1968823293_Submodel-MINI-ANT-TYPED-H_1968823293_part_DesignRootModel_PCB_ESP32-C3-MINI-1_V1(2)_PCB_E
placementOutline-5^Submodel-noModelForPart_MINI-ANT-TYPED-H_1968823293_Submodel-MINI-ANT-TYPED-H_1968823293_part_DesignRootModel_PCB_ESP32-C3-MINI-1_V1(2)_PCB_E
trace_4^Submodel-MINI-ANT-TYPED-H_1968823293_part_DesignRootModel_PCB_ESP32-C3-MINI-1_V1(2)_PCB_ESP32-C3-MINI-1_V1
trace_1^Submodel-MINI-ANT-TYPED-H_1968823293_part_DesignRootModel_PCB_ESP32-C3-MINI-1_V1(2)_PCB_ESP32-C3-MINI-1_V1
C0402_20210301.STEP^C0402_20210301.STEP_Submodel-C0402_part_DesignRootModel_PCB_ESP32-C3-MINI-1_V1(2)_PCB_ESP32-C3-MINI-1_V1
C0201_20210301.STEP^C0201_20210301.STEP_Submodel-C0201_part_DesignRootModel_PCB_ESP32-C3-MINI-1_V1(2)_PCB_ESP32-C3-MINI-1_V1 x 11
L0201_20210301.STEP^L0201_20210301.STEP_Submodel-L0201_part_DesignRootModel_PCB_ESP32-C3-MINI-1_V1(2)_PCB_ESP32-C3-MINI-1_V1 x 2
XTAL3225_20210301.STEP^XTAL3225_20210301.STEP_Submodel-XTAL3225_part_DesignRootModel_PCB_ESP32-C3-MINI-1_V1(2)_PCB_ESP32-C3-MINI-1_V1
ESP32-C3_20210301.STEP^ESP32-C3_20210301.STEP_Submodel-QFN32_0P5_5_part_DesignRootModel_PCB_ESP32-C3-MINI-1_V1(2)_PCB_ESP32-C3-MINI-1_V1
uid__4^DesignRootModel_PCB_ESP32-C3-MINI-1_V1(2)_PCB_ESP32-C3-MINI-1_V1
uid__4-22^DesignRootModel_PCB_ESP32-C3-MINI-1_V1(2)_PCB_ESP32-C3-MINI-1_V1
uid__4-23^DesignRootModel_PCB_ESP32-C3-MINI-1_V1(2)_PCB_ESP32-C3-MINI-1_V1
uid__4-24^DesignRootModel_PCB_ESP32-C3-MINI-1_V1(2)_PCB_ESP32-C3-MINI-1_V1
uid__4-25^DesignRootModel_PCB_ESP32-C3-MINI-1_V1(2)_PCB_ESP32-C3-MINI-1_V1
uid__4-26^DesignRootModel_PCB_ESP32-C3-MINI-1_V1(2)_PCB_ESP32-C3-MINI-1_V1
uid__4-27^DesignRootModel_PCB_ESP32-C3-MINI-1_V1(2)_PCB_ESP32-C3-MINI-1_V1
uid__4-28^DesignRootModel_PCB_ESP32-C3-MINI-1_V1(2)_PCB_ESP32-C3-MINI-1_V1
uid__4-29^DesignRootModel_PCB_ESP32-C3-MINI-1_V1(2)_PCB_ESP32-C3-MINI-1_V1
uid__4-30^DesignRootModel_PCB_ESP32-C3-MINI-1_V1(2)_PCB_ESP32-C3-MINI-1_V1
uid__4-31^DesignRootModel_PCB_ESP32-C3-MINI-1_V1(2)_PCB_ESP32-C3-MINI-1_V1
uid__4-32^DesignRootModel_PCB_ESP32-C3-MINI-1_V1(2)_PCB_ESP32-C3-MINI-1_V1
uid__4-33^DesignRootModel_PCB_ESP32-C3-MINI-1_V1(2)_PCB_ESP32-C3-MINI-1_V1
uid__4-34^DesignRootModel_PCB_ESP32-C3-MINI-1_V1(2)_PCB_ESP32-C3-MINI-1_V1
uid__4-35^DesignRootModel_PCB_ESP32-C3-MINI-1_V1(2)_PCB_ESP32-C3-MINI-1_V1
uid__4-36^DesignRootModel_PCB_ESP32-C3-MINI-1_V1(2)_PCB_ESP32-C3-MINI-1_V1
uid__4-37^DesignRootModel_PCB_ESP32-C3-MINI-1_V1(2)_PCB_ESP32-C3-MINI-1_V1
uid__4-38^DesignRootModel_PCB_ESP32-C3-MINI-1_V1(2)_PCB_ESP32-C3-MINI-1_V1
uid__4-39^DesignRootModel_PCB_ESP32-C3-MINI-1_V1(2)_PCB_ESP32-C3-MINI-1_V1
uid__4-40^DesignRootModel_PCB_ESP32-C3-MINI-1_V1(2)_PCB_ESP32-C3-MINI-1_V1
uid__4-41^DesignRootModel_PCB_ESP32-C3-MINI-1_V1(2)_PCB_ESP32-C3-MINI-1_V1
uid__4-42^DesignRootModel_PCB_ESP32-C3-MINI-1_V1(2)_PCB_ESP32-C3-MINI-1_V1
uid__4-43^DesignRootModel_PCB_ESP32-C3-MINI-1_V1(2)_PCB_ESP32-C3-MINI-1_V1
uid__4-44^DesignRootModel_PCB_ESP32-C3-MINI-1_V1(2)_PCB_ESP32-C3-MINI-1_V1
uid__4-45^DesignRootModel_PCB_ESP32-C3-MINI-1_V1(2)_PCB_ESP32-C3-MINI-1_V1
uid__4-46^DesignRootModel_PCB_ESP32-C3-MINI-1_V1(2)_PCB_ESP32-C3-MINI-1_V1
uid__4-47^DesignRootModel_PCB_ESP32-C3-MINI-1_V1(2)_PCB_ESP32-C3-MINI-1_V1
uid__4-48^DesignRootModel_PCB_ESP32-C3-MINI-1_V1(2)_PCB_ESP32-C3-MINI-1_V1
uid__4-49^DesignRootModel_PCB_ESP32-C3-MINI-1_V1(2)_PCB_ESP32-C3-MINI-1_V1
uid__4-50^DesignRootModel_PCB_ESP32-C3-MINI-1_V1(2)_PCB_ESP32-C3-MINI-1_V1
uid__4-51^DesignRootModel_PCB_ESP32-C3-MINI-1_V1(2)_PCB_ESP32-C3-MINI-1_V1
uid__4-52^DesignRootModel_PCB_ESP32-C3-MINI-1_V1(2)_PCB_ESP32-C3-MINI-1_V1
uid__4-53^DesignRootModel_PCB_ESP32-C3-MINI-1_V1(2)_PCB_ESP32-C3-MINI-1_V1
uid__4-54^DesignRootModel_PCB_ESP32-C3-MINI-1_V1(2)_PCB_ESP32-C3-MINI-1_V1
uid__4-55^DesignRootModel_PCB_ESP32-C3-MINI-1_V1(2)_PCB_ESP32-C3-MINI-1_V1
uid__4-56^DesignRootModel_PCB_ESP32-C3-MINI-1_V1(2)_PCB_ESP32-C3-MINI-1_V1
uid__4-57^DesignRootModel_PCB_ESP32-C3-MINI-1_V1(2)_PCB_ESP32-C3-MINI-1_V1
uid__4-58^DesignRootModel_PCB_ESP32-C3-MINI-1_V1(2)_PCB_ESP32-C3-MINI-1_V1
uid__4-59^DesignRootModel_PCB_ESP32-C3-MINI-1_V1(2)_PCB_ESP32-C3-MINI-1_V1
uid__4-60^DesignRootModel_PCB_ESP32-C3-MINI-1_V1(2)_PCB_ESP32-C3-MINI-1_V1
uid__4-61^DesignRootModel_PCB_ESP32-C3-MINI-1_V1(2)_PCB_ESP32-C3-MINI-1_V1
uid__4-62^DesignRootModel_PCB_ESP32-C3-MINI-1_V1(2)_PCB_ESP32-C3-MINI-1_V1
uid__4-63^DesignRootModel_PCB_ESP32-C3-MINI-1_V1(2)_PCB_ESP32-C3-MINI-1_V1
uid__4-64^DesignRootModel_PCB_ESP32-C3-MINI-1_V1(2)_PCB_ESP32-C3-MINI-1_V1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

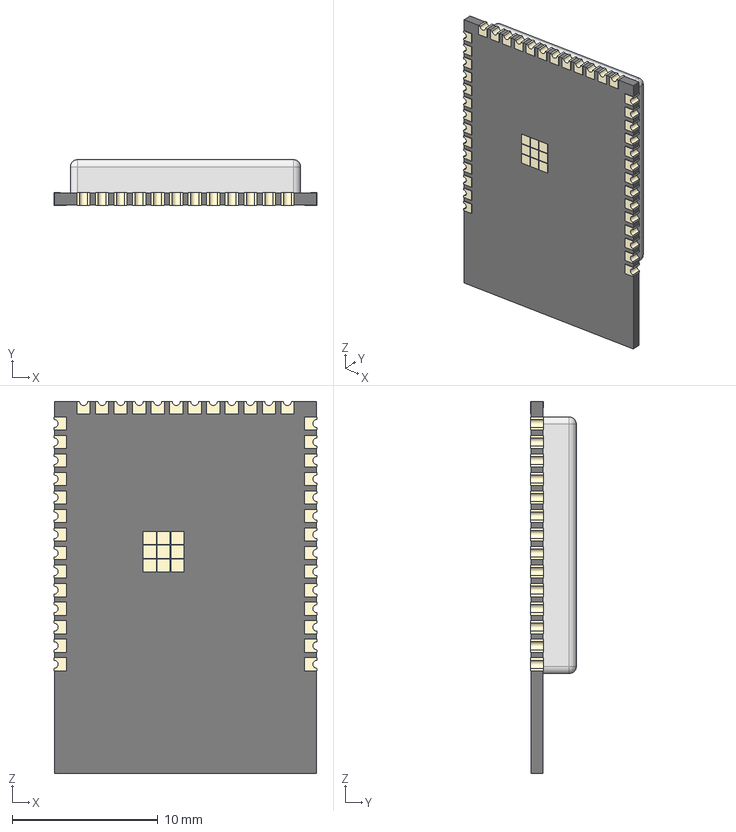
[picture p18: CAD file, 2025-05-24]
versions/v7-raw-34/3dmodels/ESP32-S3-WROOM.step
18.0 x 3.16 x 25.5 mm
ESP-S3-WROOM_via x 26
ESP32-S3-WROOM_shell
ESP32-S3-WROOM_body
ESP-S3-WROOM_via v3(镜像) x 14

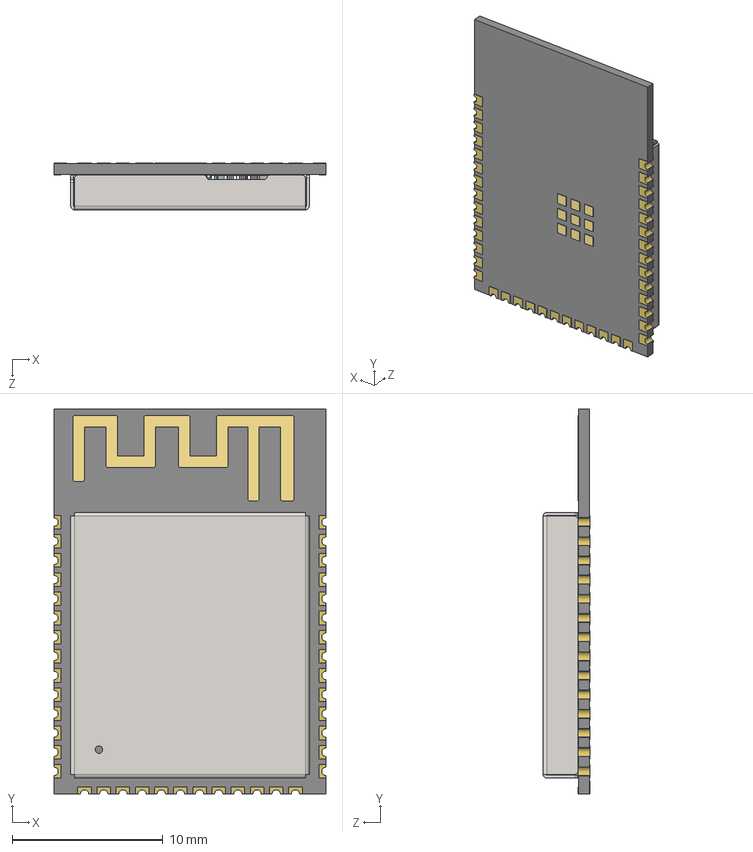
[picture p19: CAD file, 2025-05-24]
versions/v7-raw-34/kicad-libraries/3d/ESP32-S3-WROOM-1.STEP
18.0 x 25.5 x 3.10 mm
C0201_20210301.STEP^C0201_20210301.STEP_Submodel-C0201_part_DesignRootModel_PCB_ESP32-S3-WROOM-1_V1(2)_PCB_ESP32-S3-WROOM-1_V1 x 14
L0201_20210301.STEP^L0201_20210301.STEP_Submodel-L0201_part_DesignRootModel_PCB_ESP32-S3-WROOM-1_V1(2)_PCB_ESP32-S3-WROOM-1_V1 x 3
C0402_20210301.STEP^C0402_20210301.STEP_Submodel-C0402_part_DesignRootModel_PCB_ESP32-S3-WROOM-1_V1(2)_PCB_ESP32-S3-WROOM-1_V1
R0201_20210301.STEP^R0201_20210301.STEP_Submodel-R0201_part_DesignRootModel_PCB_ESP32-S3-WROOM-1_V1(2)_PCB_ESP32-S3-WROOM-1_V1 x 8
trace_1^Submodel-MINI-ANT-TYPEB_668419613_part_DesignRootModel_PCB_ESP32-S3-WROOM-1_V1(2)_PCB_ESP32-S3-WROOM-1_V1
DFN1006.STEP^DFN1006.STEP_Submodel-SOD882_part_DesignRootModel_PCB_ESP32-S3-WROOM-1_V1(2)_PCB_ESP32-S3-WROOM-1_V1
SOP8_rev1_20210308.STEP^SOP8_rev1_20210308.STEP_Submodel-SOP8_1P27_6P6_part_DesignRootModel_PCB_ESP32-S3-WROOM-1_V1(2)_PCB_ESP32-S3-WROOM-1_V1
XTAL3225_20210301.STEP^XTAL3225_20210301.STEP_Submodel-XTAL3225_part_DesignRootModel_PCB_ESP32-S3-WROOM-1_V1(2)_PCB_ESP32-S3-WROOM-1_V1
ESP32-S3_20210301.STEP^ESP32-S3_20210301.STEP_Submodel-QFN56_0P4_7_part_DesignRootModel_PCB_ESP32-S3-WROOM-1_V1(2)_PCB_ESP32-S3-WROOM-1_V1
uid__4-128^DesignRootModel_PCB_ESP32-S3-WROOM-1_V1(2)_PCB_ESP32-S3-WROOM-1_V1
uid__4-129^DesignRootModel_PCB_ESP32-S3-WROOM-1_V1(2)_PCB_ESP32-S3-WROOM-1_V1
uid__4-130^DesignRootModel_PCB_ESP32-S3-WROOM-1_V1(2)_PCB_ESP32-S3-WROOM-1_V1
uid__4-149^DesignRootModel_PCB_ESP32-S3-WROOM-1_V1(2)_PCB_ESP32-S3-WROOM-1_V1
uid__4-150^DesignRootModel_PCB_ESP32-S3-WROOM-1_V1(2)_PCB_ESP32-S3-WROOM-1_V1
uid__4-151^DesignRootModel_PCB_ESP32-S3-WROOM-1_V1(2)_PCB_ESP32-S3-WROOM-1_V1
uid__4-167^DesignRootModel_PCB_ESP32-S3-WROOM-1_V1(2)_PCB_ESP32-S3-WROOM-1_V1
uid__4-168^DesignRootModel_PCB_ESP32-S3-WROOM-1_V1(2)_PCB_ESP32-S3-WROOM-1_V1
uid__4-169^DesignRootModel_PCB_ESP32-S3-WROOM-1_V1(2)_PCB_ESP32-S3-WROOM-1_V1
uid__1-279^DesignRootModel_PCB_ESP32-S3-WROOM-1_V1(2)_PCB_ESP32-S3-WROOM-1_V1
uid__1-280^DesignRootModel_PCB_ESP32-S3-WROOM-1_V1(2)_PCB_ESP32-S3-WROOM-1_V1
uid__1-292^DesignRootModel_PCB_ESP32-S3-WROOM-1_V1(2)_PCB_ESP32-S3-WROOM-1_V1
uid__1-298^DesignRootModel_PCB_ESP32-S3-WROOM-1_V1(2)_PCB_ESP32-S3-WROOM-1_V1
uid__1-299^DesignRootModel_PCB_ESP32-S3-WROOM-1_V1(2)_PCB_ESP32-S3-WROOM-1_V1
uid__1-300^DesignRootModel_PCB_ESP32-S3-WROOM-1_V1(2)_PCB_ESP32-S3-WROOM-1_V1
uid__1-301^DesignRootModel_PCB_ESP32-S3-WROOM-1_V1(2)_PCB_ESP32-S3-WROOM-1_V1
uid__1-304^DesignRootModel_PCB_ESP32-S3-WROOM-1_V1(2)_PCB_ESP32-S3-WROOM-1_V1
uid__1-305^DesignRootModel_PCB_ESP32-S3-WROOM-1_V1(2)_PCB_ESP32-S3-WROOM-1_V1
uid__1-308^DesignRootModel_PCB_ESP32-S3-WROOM-1_V1(2)_PCB_ESP32-S3-WROOM-1_V1
uid__1-310^DesignRootModel_PCB_ESP32-S3-WROOM-1_V1(2)_PCB_ESP32-S3-WROOM-1_V1
uid__1-311^DesignRootModel_PCB_ESP32-S3-WROOM-1_V1(2)_PCB_ESP32-S3-WROOM-1_V1
uid__1-325^DesignRootModel_PCB_ESP32-S3-WROOM-1_V1(2)_PCB_ESP32-S3-WROOM-1_V1
uid__1-334^DesignRootModel_PCB_ESP32-S3-WROOM-1_V1(2)_PCB_ESP32-S3-WROOM-1_V1
uid__1-338^DesignRootModel_PCB_ESP32-S3-WROOM-1_V1(2)_PCB_ESP32-S3-WROOM-1_V1
uid__1-339^DesignRootModel_PCB_ESP32-S3-WROOM-1_V1(2)_PCB_ESP32-S3-WROOM-1_V1
uid__1-340^DesignRootModel_PCB_ESP32-S3-WROOM-1_V1(2)_PCB_ESP32-S3-WROOM-1_V1
uid__1-343^DesignRootModel_PCB_ESP32-S3-WROOM-1_V1(2)_PCB_ESP32-S3-WROOM-1_V1
uid__1-344^DesignRootModel_PCB_ESP32-S3-WROOM-1_V1(2)_PCB_ESP32-S3-WROOM-1_V1
uid__1-345^DesignRootModel_PCB_ESP32-S3-WROOM-1_V1(2)_PCB_ESP32-S3-WROOM-1_V1
uid__1-352^DesignRootModel_PCB_ESP32-S3-WROOM-1_V1(2)_PCB_ESP32-S3-WROOM-1_V1
uid__1-354^DesignRootModel_PCB_ESP32-S3-WROOM-1_V1(2)_PCB_ESP32-S3-WROOM-1_V1
uid__1-355^DesignRootModel_PCB_ESP32-S3-WROOM-1_V1(2)_PCB_ESP32-S3-WROOM-1_V1
uid__1-357^DesignRootModel_PCB_ESP32-S3-WROOM-1_V1(2)_PCB_ESP32-S3-WROOM-1_V1
uid__1-358^DesignRootModel_PCB_ESP32-S3-WROOM-1_V1(2)_PCB_ESP32-S3-WROOM-1_V1
uid__1-359^DesignRootModel_PCB_ESP32-S3-WROOM-1_V1(2)_PCB_ESP32-S3-WROOM-1_V1
uid__1-364^DesignRootModel_PCB_ESP32-S3-WROOM-1_V1(2)_PCB_ESP32-S3-WROOM-1_V1
uid__1-365^DesignRootModel_PCB_ESP32-S3-WROOM-1_V1(2)_PCB_ESP32-S3-WROOM-1_V1
uid__1-371^DesignRootModel_PCB_ESP32-S3-WROOM-1_V1(2)_PCB_ESP32-S3-WROOM-1_V1
uid__1-375^DesignRootModel_PCB_ESP32-S3-WROOM-1_V1(2)_PCB_ESP32-S3-WROOM-1_V1
uid__1-376^DesignRootModel_PCB_ESP32-S3-WROOM-1_V1(2)_PCB_ESP32-S3-WROOM-1_V1
uid__1-378^DesignRootModel_PCB_ESP32-S3-WROOM-1_V1(2)_PCB_ESP32-S3-WROOM-1_V1
uid__1-379^DesignRootModel_PCB_ESP32-S3-WROOM-1_V1(2)_PCB_ESP32-S3-WROOM-1_V1
uid__1-380^DesignRootModel_PCB_ESP32-S3-WROOM-1_V1(2)_PCB_ESP32-S3-WROOM-1_V1
uid__1-381^DesignRootModel_PCB_ESP32-S3-WROOM-1_V1(2)_PCB_ESP32-S3-WROOM-1_V1
uid__1-382^DesignRootModel_PCB_ESP32-S3-WROOM-1_V1(2)_PCB_ESP32-S3-WROOM-1_V1
uid__1-383^DesignRootModel_PCB_ESP32-S3-WROOM-1_V1(2)_PCB_ESP32-S3-WROOM-1_V1
uid__1-384^DesignRootModel_PCB_ESP32-S3-WROOM-1_V1(2)_PCB_ESP32-S3-WROOM-1_V1
uid__1-385^DesignRootModel_PCB_ESP32-S3-WROOM-1_V1(2)_PCB_ESP32-S3-WROOM-1_V1
uid__1-386^DesignRootModel_PCB_ESP32-S3-WROOM-1_V1(2)_PCB_ESP32-S3-WROOM-1_V1
uid__1-387^DesignRootModel_PCB_ESP32-S3-WROOM-1_V1(2)_PCB_ESP32-S3-WROOM-1_V1
uid__1-388^DesignRootModel_PCB_ESP32-S3-WROOM-1_V1(2)_PCB_ESP32-S3-WROOM-1_V1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

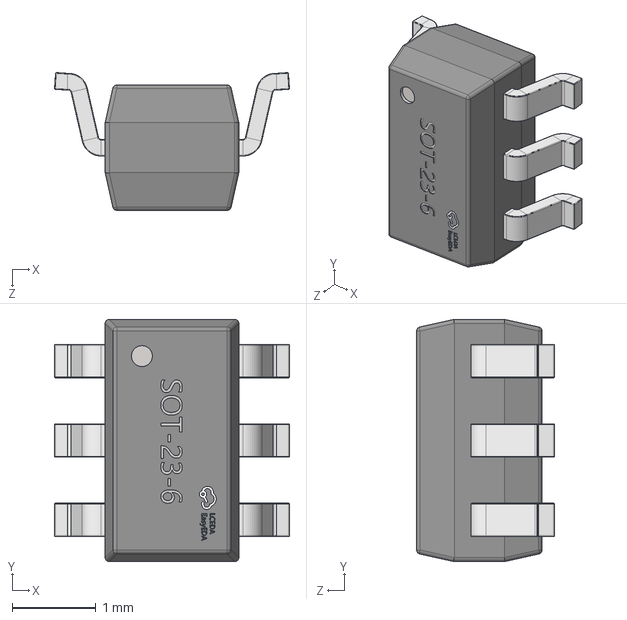
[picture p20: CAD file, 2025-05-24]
versions/v7-raw-34/3dmodels/SOT-23-6_RY3730_Led_PWM.step
2.81 x 2.90 x 1.65 mm

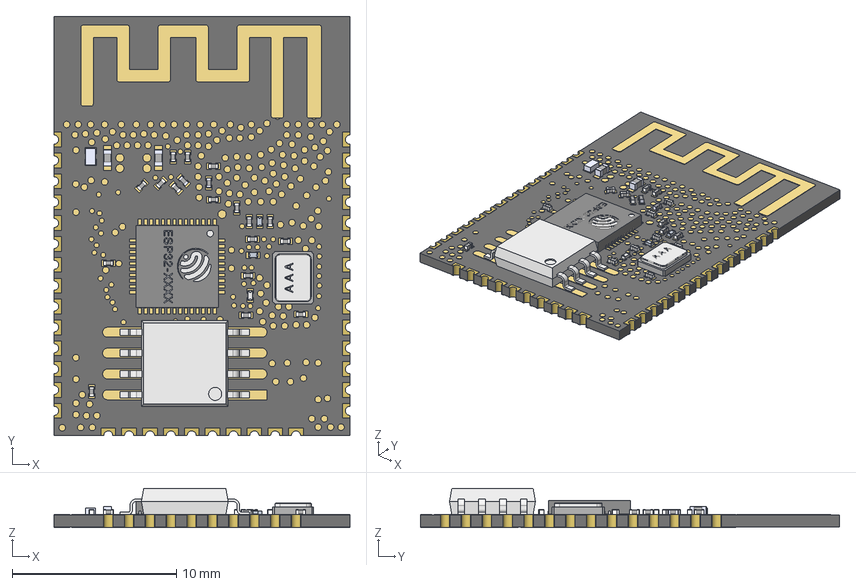
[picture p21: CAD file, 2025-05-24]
versions/v7-raw-34/kicad-libraries/3d/ESP32-WROOM-32E_No-Cover.STEP
18.0 x 25.5 x 2.40 mm
ESP32_5x5_20210301.STEP^ESP32_5x5_20210301.STEP_Submodel-SLP48_5X5_ part_DesignRootModel_PCB_ESP32-WROOM-32E_V1(2)_PCB_ESP32-WROOM-32E_V1
trace_1^Submodel-ANT_L_TYPEA_1501846164_part_DesignRootModel_PCB_ ESP32-WROOM-32E_V1(2)_PCB_ESP32-WROOM-32E_V1
DFN1006.STEP^DFN1006.STEP_Submodel-SOD882_part_DesignRootModel_PCB_ ESP32-WROOM-32E_V1(2)_PCB_ESP32-WROOM-32E_V1
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

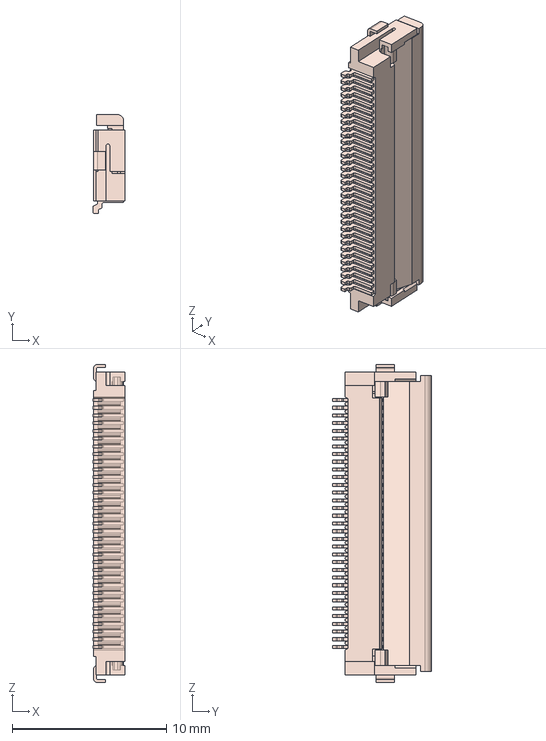
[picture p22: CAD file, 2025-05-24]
versions/v7-raw-34/3dmodels/FH12-33S-0.5SH.stp
2.10 x 6.40 x 20.6 mm

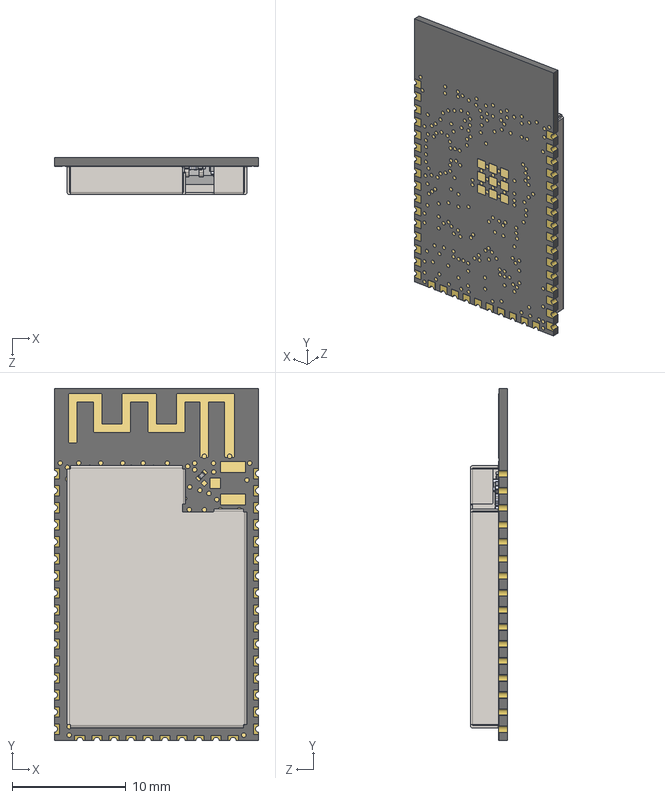
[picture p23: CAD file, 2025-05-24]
versions/v7-raw-34/kicad-libraries/3d/ESP32-S2-WROVER.STEP
18.0 x 31.0 x 3.30 mm
ESP32-S2_20210301.STEP^ESP32-S2_20210301.STEP_Submodel-QFN56_0P4_7_part_DesignRootModel_PCB_ESP32-S2-WROOM_V1(2)_PCB_ESP32-S2-WROOM_V1
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

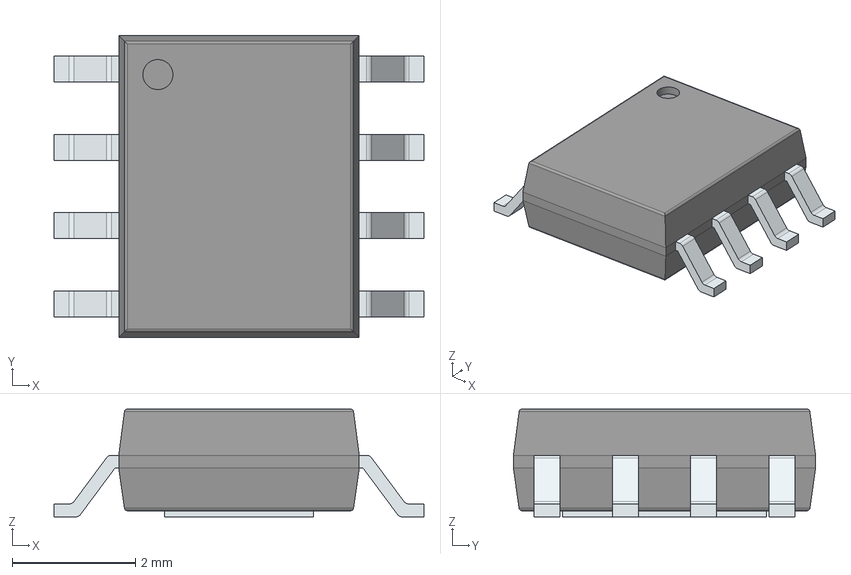
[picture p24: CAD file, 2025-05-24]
versions/v7-raw-34/3dmodels/TP4056-42-ESOP8.step
6.00 x 4.90 x 1.75 mm
PinsArrayLR
ThermalPad

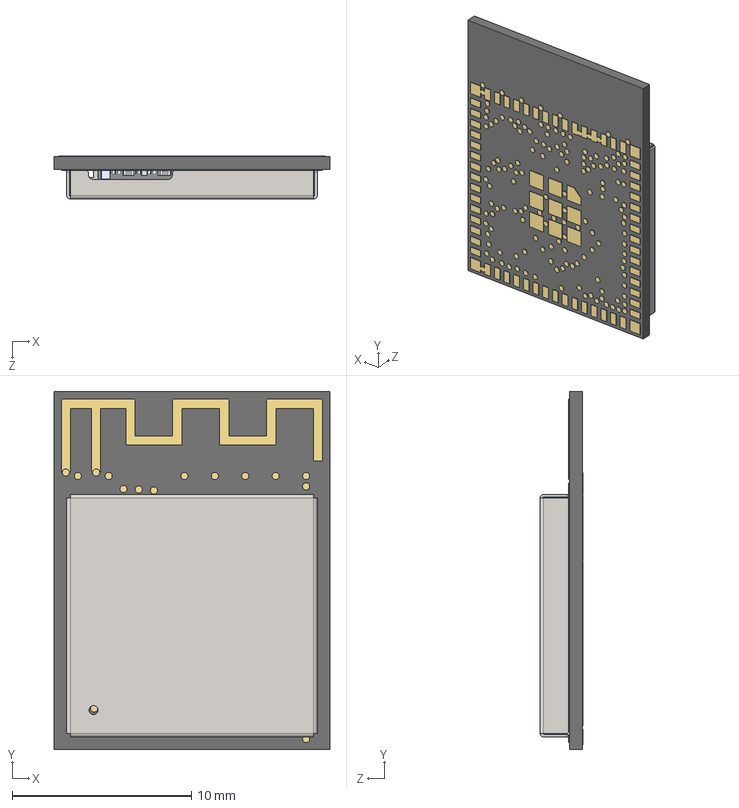
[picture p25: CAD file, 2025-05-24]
versions/v7-raw-34/kicad-libraries/3d/ESP32-S2-MINI-1.STEP
15.4 x 20.0 x 2.40 mm
DFN1006.STEP^DFN1006.STEP_Submodel-SOD882_part_DesignRootModel_PCB_ESP32-S2-MINI-1_V1(2)_PCB_ESP32-S2-MINI-1_V1
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

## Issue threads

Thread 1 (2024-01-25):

Build a Kaleido Eink board with touch and FL support

martinberlin, 2024-01-25:
Building a v7 clone that will be tracked in this issue.
The board still needs to go through many layers and peer reviews before version 1.0 can be sent from fabrication.

I will also blog about the project since JLCPCB, my service provider, is interested to see how is my design process and their engineers where very helpful so far with the epdiy PCB production line. This so far is a very raw take, I just extended v7, and added the connectors in the right positions.

Some facts that we need to take in account in this first revision:

1. **Touch 8 pin FPC and Front-light (FL) 6 pin connector** need to be double checked since at this moment I still do not have the display in my hand. Maybe @bitbank2 can help there to check if the number 1 coincides with the 1 in the display connector (I do not want to send this to fabrication without double-checking this)
2. Focus in this 1.0 is to get display and touch working if possible without any extra fixes. If there must be a wire flying over is not a problem, that is why is Rev. 1.0
3. FL connections are wired, but there is not a 17 V (voltage in page 14 of datasheet) booster circuit in this revision, Cathodes have been connected to GND. Theoretically we can try the FL connecting the +15 Volts that feed the pixels to preview how is going to be.
4. I quite dislike how is the FL 6 pin connector in this version of Kaleido. It's super close to the display connector when you bend it, making quite impossible to place in the PCB due to yard requirements of the 34 pin connector.

But that should be by no means the FL power supply. A proper independent boost circuit should be prepared with a Load switch or similar that completely cuts the input power (Since otherwise it will leak and consume when FL is powered OFF)
If the first iteration works, in Rev 1.1 we could add the boost-circuit, plus a P-Channel mosfet that will let GND pass, and can be controlled by a PWM GPIO from the S3 (So we can regulate screen brightness, with this 2 channels)

Marcus on your end can you confirm what is the difference between this 2 LED circuits?
It's one white LED and the other more Warm?

PREVIEWS
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
Back cooper:
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

Touch (Quite sure got the pins inverted, 8 should be 1)
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
Needs correction

martinberlin, 2024-01-27:
Added in **1/add-fl-pwm** branch a proposed circuit that I know to work (Only BOOST circuit) using [MT3608](https://www.olimex.com/Products/Breadboarding/BB-PWR-3608/resources/MT3608.pdf)

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

Then there are 3 control IOs:
- GPIO10: EN_FL_POWER on high it will enable the boost chip, generating stable 17 V after 10 ms.
- GPIO11 & 12: PWM channels so it connects GND via a NPN Transistor to each of the LED circuits.

mataide, 2024-01-29:
Marcus on your end can you confirm what is the difference between these 2 LED circuits?

@martinberlin Yes, one circuit is for white LED and the other is Warm.

martinberlin, 2024-01-30:
Thanks @mataide
If possible please submit a review from your team by Thursday 1 Feb 14:00 so I have time to route the FL boost circuit.
Otherwise is no problem but it will be then sent to fabrication 14 to 15 February as next possible date

Jvinicius06, 2024-01-30:
I believe the position of the FP connector is not in a good position for connection because, as you can see in the display drawing, the connector is next to the touch connector.

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

martinberlin, 2024-01-30:
@Jvinicius06 the thing is that the display I've has a [different setup](https://mastodon.social/@fasani/111823599852523245) for the FL cable. That's why it's on that position in the PCB.
If it works then on a next revision I will add also a second connector to support both models

mataide, 2024-01-30:
@martinberlin You should consider that you are going to receive the model **EC060KH5**, the old one is not available anymore.

Jvinicius06, 2024-01-31:
In this case, what do you mean the FP connector is different? Isn't it better to put 2 connectors in parallel?

martinberlin, 2024-01-31:
Not really in this case since I'm creating a PCB for @mataide which uses the EC060KH5 model.
Now this PCB comes from an open source project and it will be open source. So if anyone wants to modify it can do it considering the License that specifies that versions from this project should be also open source

martinberlin, 2024-01-31:
@mataide routed the 17 V booster and PWM circuit. KiCad files updated in the branch **1/add-fl-pwm**
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

martinberlin, 2024-02-02:
Sent to fabrication yesterday.  Here the JLCPCB corrected part placement (Always one or two parts are rotated and adjusted by their engineering team before entering the Pick and Place data)
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

Closed 2024-04-26.

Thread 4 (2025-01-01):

Make a v7 version with optional OV2640/OV5640 camera connector

martinberlin, 2025-01-01:
Based on this schematic. There is also a product in Tindie with the adapter

https://www.tindie.com/products/johnnywu/pmod-camera-expansion-board/

[pmod-camera-v1.0.pdf](https://github.com/user-attachments/files/18285983/pmod-camera-v1.0.pdf)

IDEA::
Would like to retake my idea of testing a self made camera just for fun and showing the image after pressing the button in 16 grays on the epaper.
For preview it will make just a 1/4 small icon in MODE_DU 1 bit.

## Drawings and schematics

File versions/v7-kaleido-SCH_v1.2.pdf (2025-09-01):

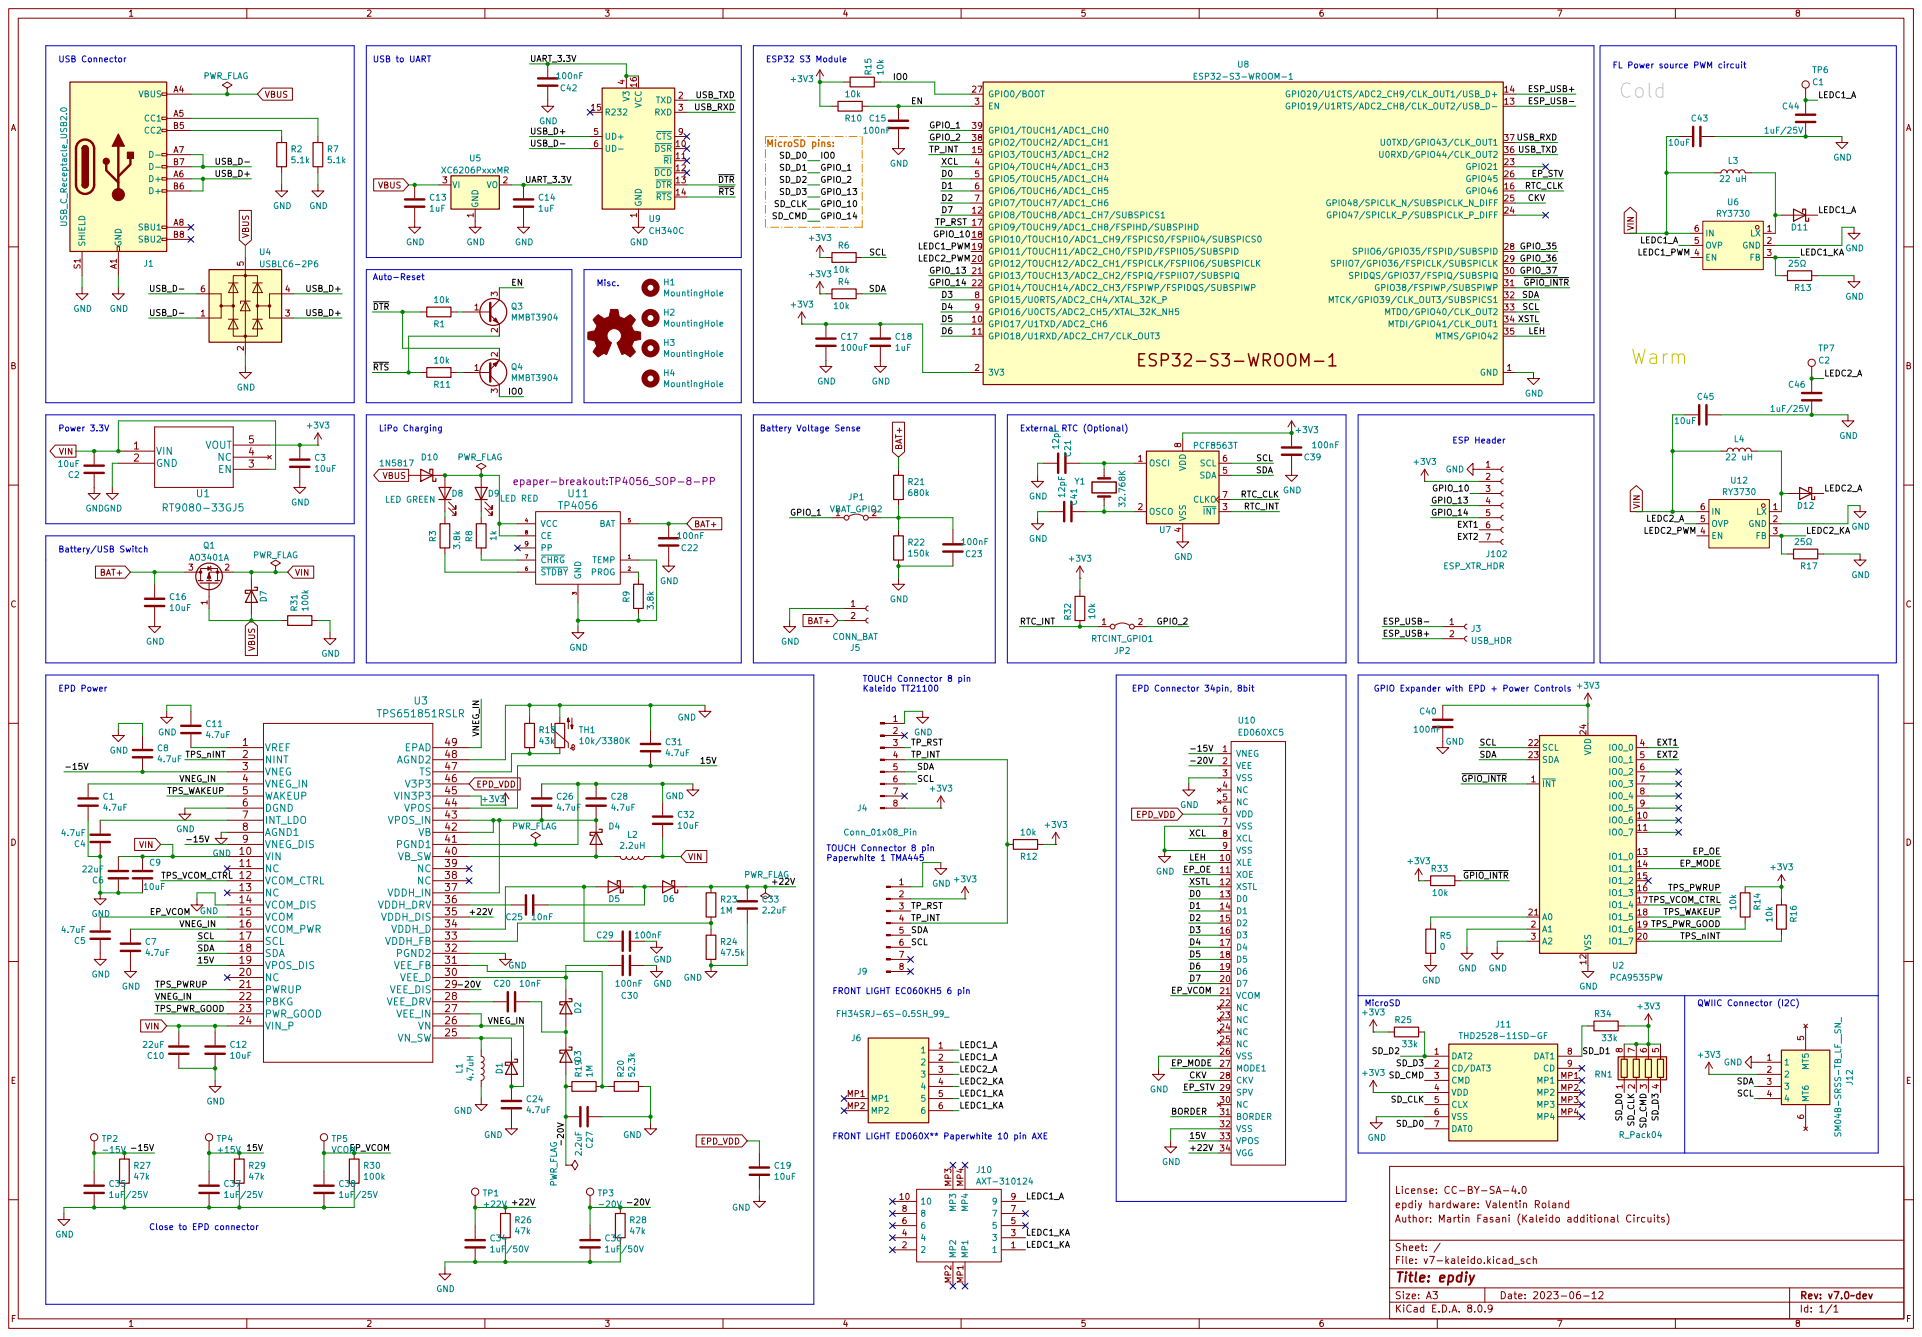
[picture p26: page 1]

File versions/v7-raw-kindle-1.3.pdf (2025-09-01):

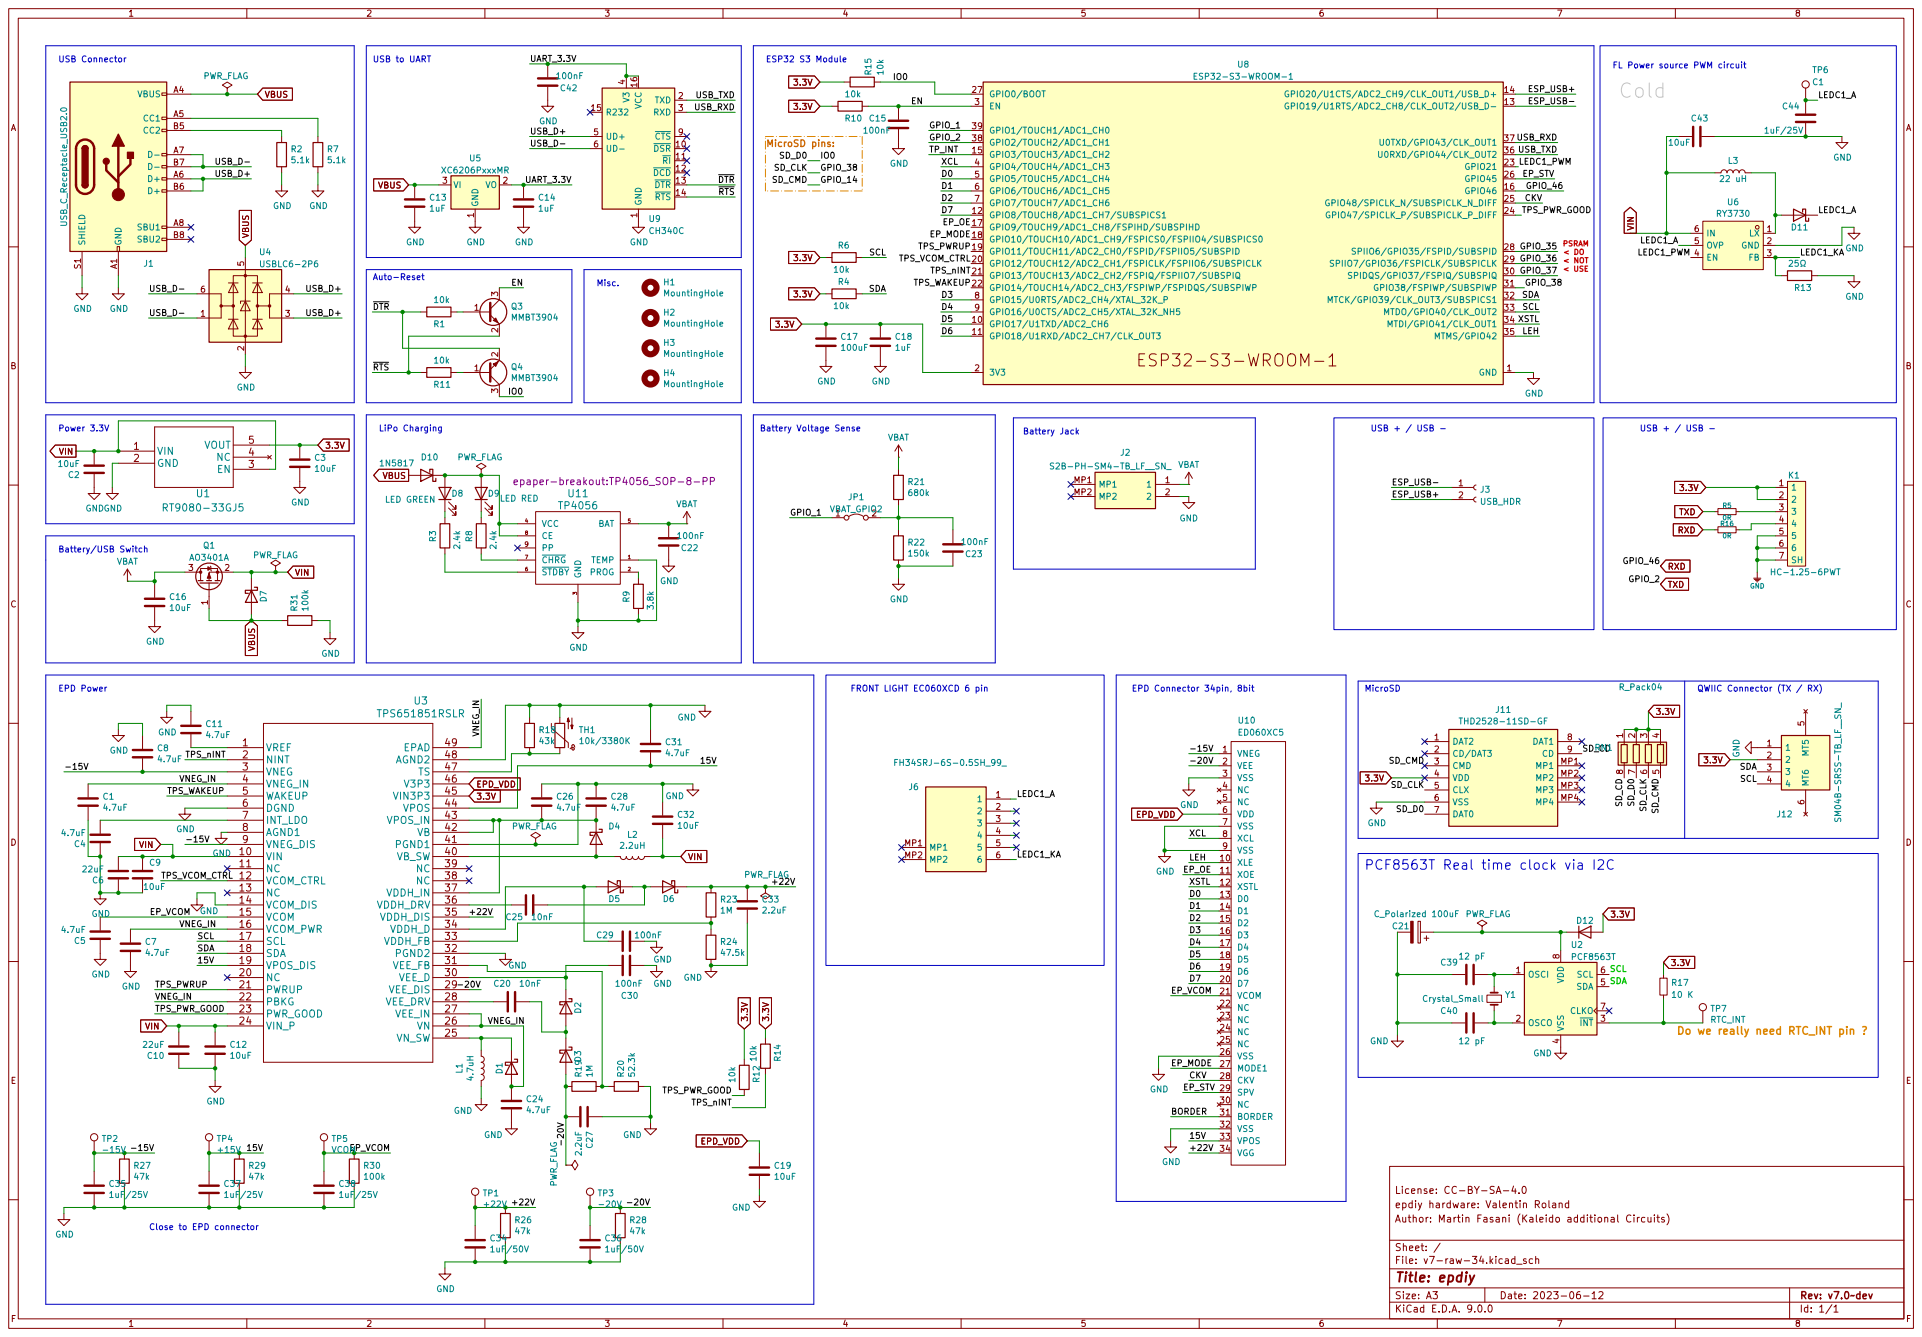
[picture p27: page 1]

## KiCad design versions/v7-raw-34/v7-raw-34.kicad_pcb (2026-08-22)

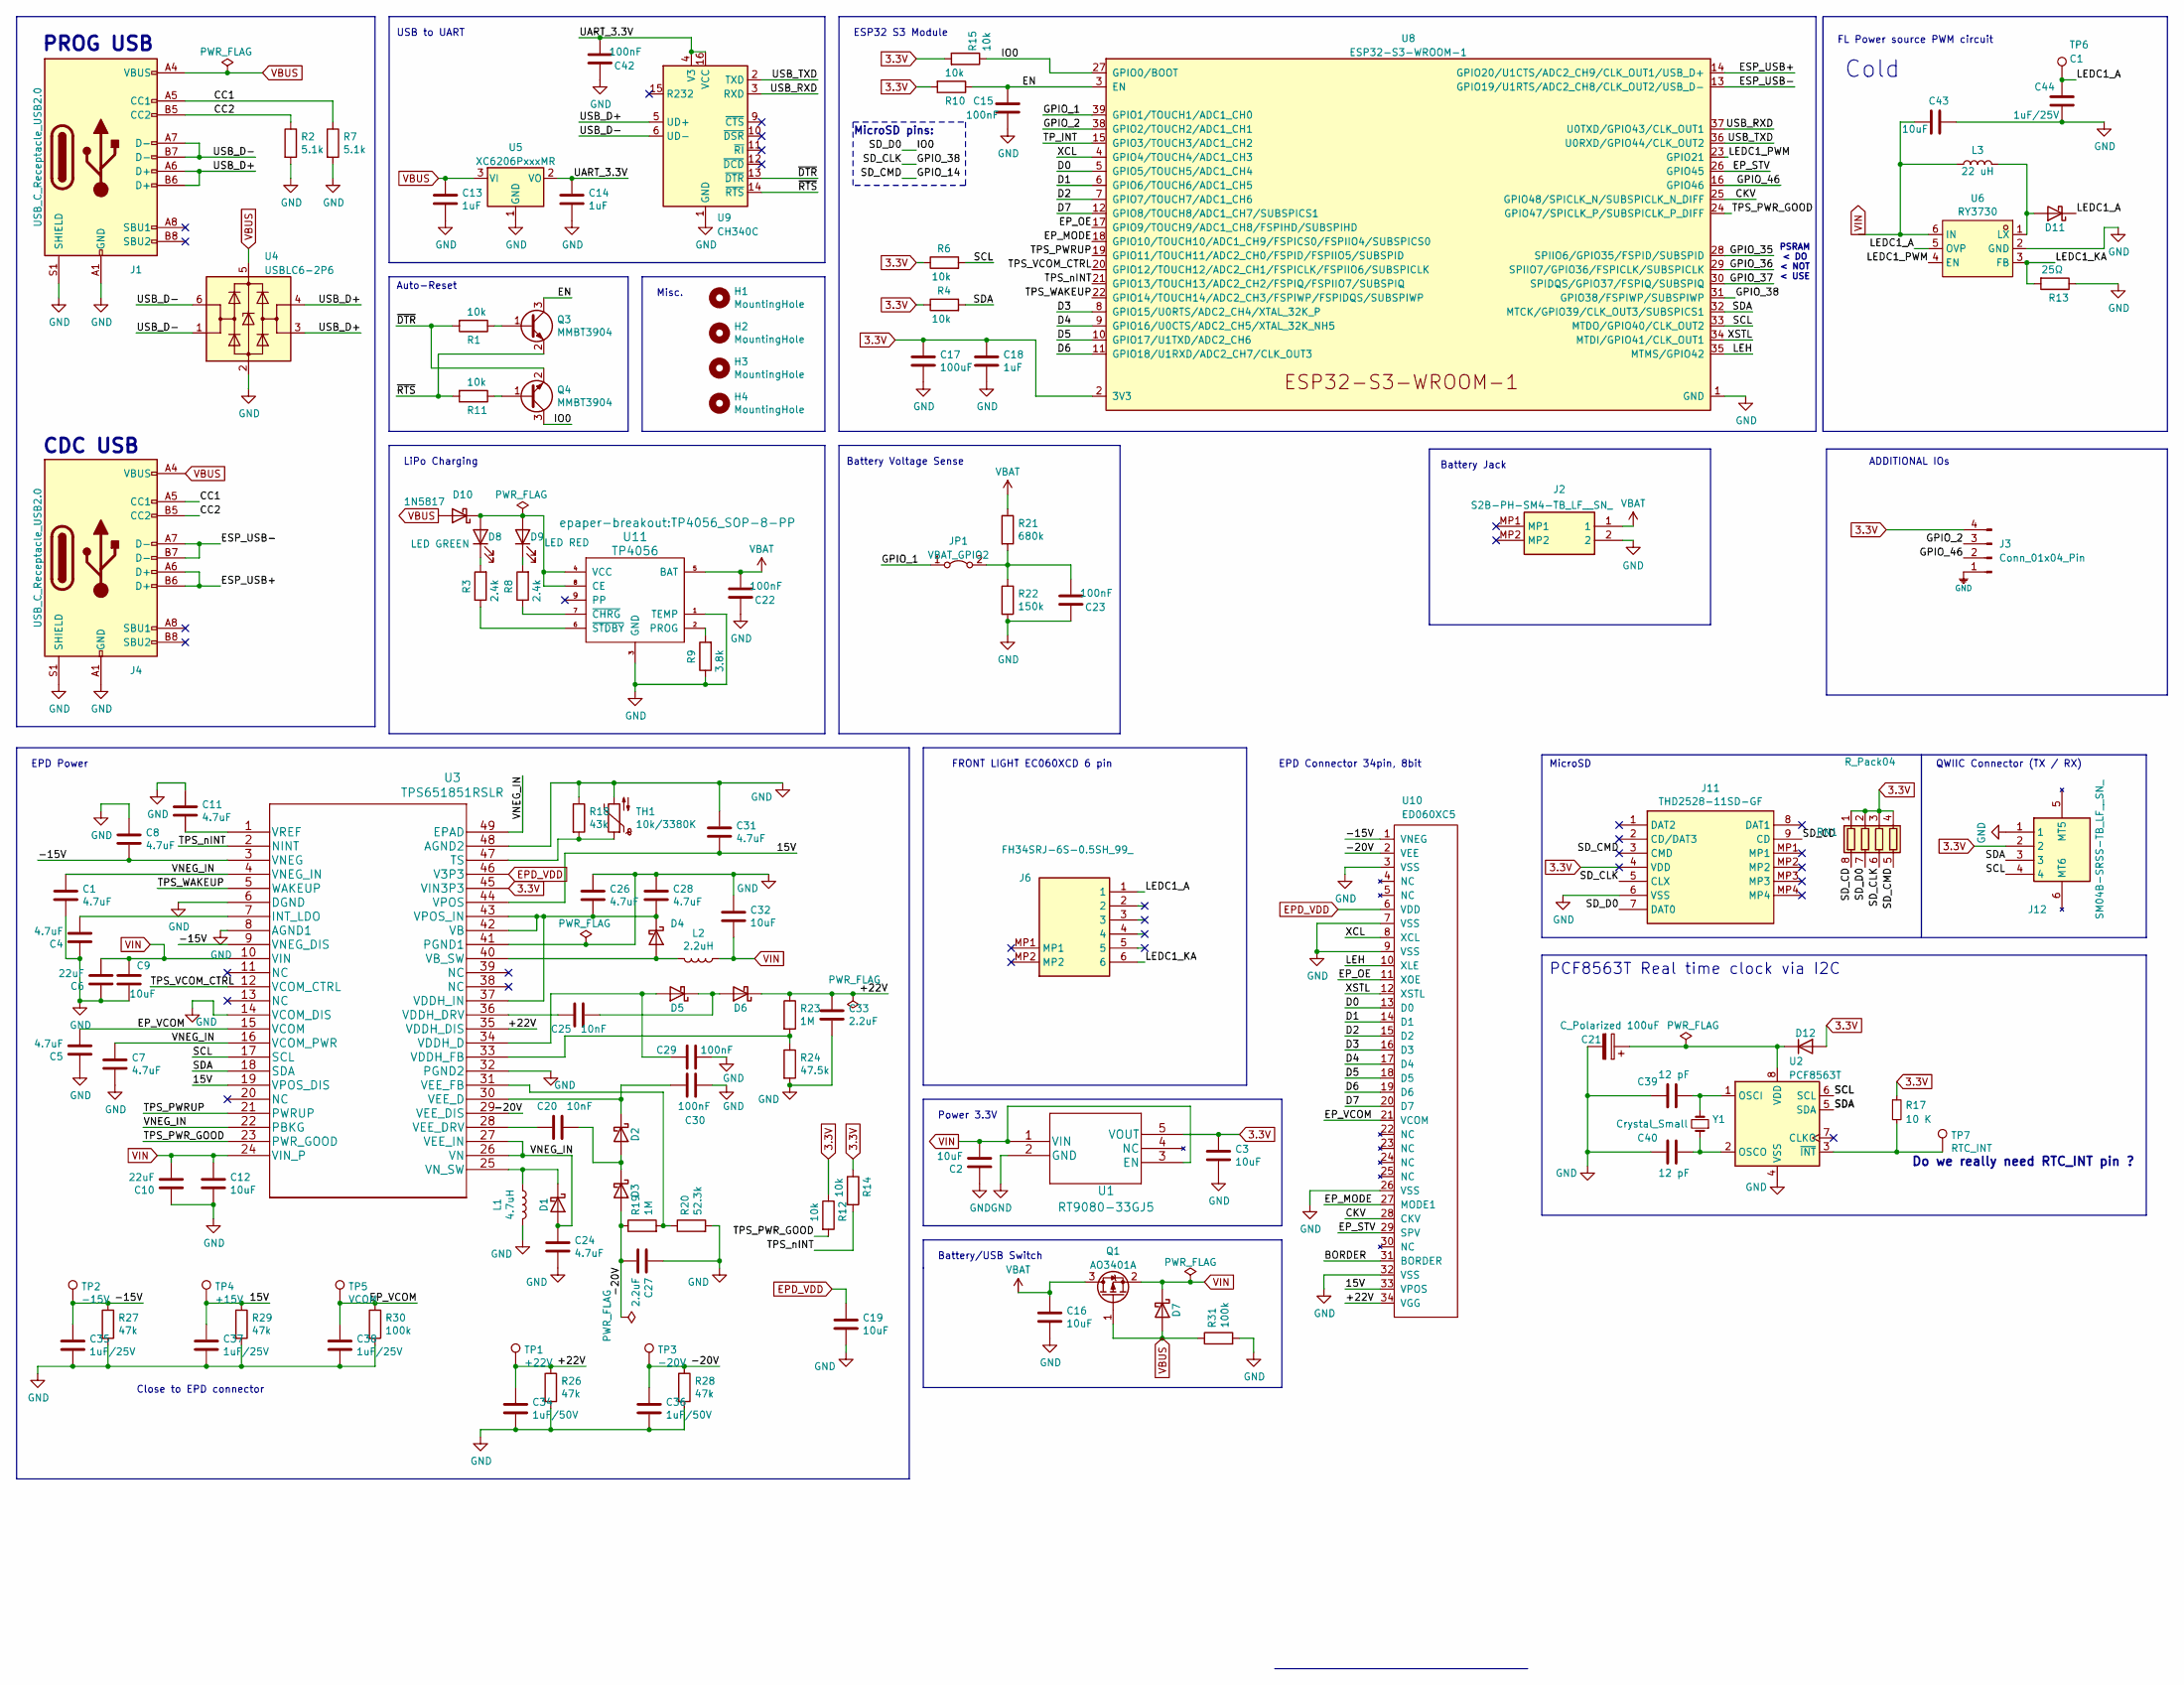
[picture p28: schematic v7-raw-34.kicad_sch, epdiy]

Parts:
C1, C4, C5, C7, C8, C11, C24, C26, C28, C31: 4.7uF; C_0805_2012Metric; LCSC C1779
C2, C3, C9, C12, C16, C19, C32, C43: 10uF; C_0805_2012Metric; LCSC C15850
C6, C10: 22uF; C_0805_2012Metric; LCSC C45783
C13, C14, C18: 1uF; C_0805_2012Metric; LCSC C28323
C15, C22, C23, C29, C30, C42: 100nF; C_0805_2012Metric; LCSC C49678
C17: 100uF; CP_EIA-3528-15_AVX-H; LCSC C16133
C20, C25: 10nF; C_0805_2012Metric; LCSC C1710
C21: C_Polarized 100uF; CP_EIA-3528-21_Kemet-B; LCSC C129289
C27, C33: 2.2uF; C_0805_2012Metric; LCSC C49217
C34, C36: 1uF/50V; C_1206_3216Metric; LCSC C1848
C35, C37, C38, C44: 1uF/25V; C_0805_2012Metric; LCSC C28323
C39, C40: 12 pF; C_0603_1608Metric; LCSC C38523
D1, D2, D3, D4, D5, D6, D7, D11: MBR0540; D_SOD-123; LCSC C21353
D8: LED GREEN; LED_0805_2012Metric; LCSC C2297
D9: LED RED; LED_0805_2012Metric; LCSC C84256
D10: 1N5817; D_SOD-123; LCSC C8598
D12: 1N4148WS; D_SOD-323; LCSC C2128
H1, H2, H3, H4: MountingHole; MountingHole_2.2mm_M2
J1, J4: USB_C_Receptacle_USB2.0; USB_C_Receptacle_HRO_TYPE-C-31-M-12; LCSC C165948
J2: S2B-PH-SM4-TB_LF__SN_; S2BPHSM4TBLFSN; Manufacturer_Part_Number S2B-PH-SM4-TB(LF)(SN); LCSC C295747
J3: Conn_01x04_Pin; PinHeader_1x04_P2.54mm_Vertical
J6: FH34SRJ-6S-0.5SH_99_; C224194_6x1_FH34SRJ-6S-0.5SH50_HIR; Manufacturer_Part_Number FH34SRJ-6S-0.5SH(99); Mouser Part Number 798-FH34SRJ6S0.5SH99
J11: THD2528-11SD-GF; THD252811SDGF; Manufacturer_Part_Number THD2528-11SD-GF; LCSC C283232
J12: SM04B-SRSS-TB_LF__SN_; QWIIC_SM04B-SRSS-TB_LFSN_; Manufacturer_Part_Number SM04B-SRSS-TB(LF)(SN); LCSC C160404
JP1: VBAT_GPIO2; SolderJumper-2_P1.3mm_Bridged2Bar_Pad1.0x1.5mm
L1: 4.7uH; L_Taiyo-Yuden_NR-50xx_HandSoldering; LCSC C222947
L2: 2.2uH; L_Taiyo-Yuden_NR-40xx_HandSoldering; LCSC C92959
L3: 22 uH; SWPA5040S282MT; LCSC C68434
Q1: AO3401A; SOT-23; LCSC C15127
Q3, Q4: MMBT3904; SOT-23; LCSC C20526
R1, R4, R6, R10, R11, R12, R14, R15: 10k; R_0603_1608Metric; LCSC C25804
R2, R7: 5.1k; R_0603_1608Metric; LCSC C23186
R3, R8: 2.4k; R_0603_1608Metric; LCSC C22940
R9: 3.8k; R_0603_1608Metric; LCSC C103591
R13: 25Ω; R_0603_1608Metric; LCSC C308324
R17: 10 K; R_0603_1608Metric; LCSC C25804
R18: 43k; R_0603_1608Metric; LCSC C23172
R19, R23: 1M; R_0603_1608Metric; LCSC C22935
R20: 52.3k; R_0603_1608Metric; LCSC C23196
R21: 680k; R_0603_1608Metric; LCSC C25822
R22: 150k; R_0603_1608Metric; LCSC C22807
R24: 47.5k; R_0603_1608Metric; LCSC C25819
R26, R27, R28, R29: 47k; R_0603_1608Metric; LCSC C25819
R30, R31: 100k; R_0603_1608Metric; LCSC C25803
RN1: R_Pack04; C425297_RES-ARRAY-SMD_0402-8P-L2.0-W1.0-BL; LCSC C425297
TH1: 10k/3380K; R_0603_1608Metric; LCSC C76589
TP1: +22V; TestPoint_Pad_D2.5mm
TP2: -15V; TestPoint_Pad_D2.5mm
TP3: -20V; TestPoint_Pad_D2.5mm
TP4: +15V; TestPoint_Pad_D2.5mm
TP5: VCOM; TestPoint_Pad_D2.5mm
TP6: C1; TestPoint_Pad_D2.5mm
TP7: RTC_INT; TestPoint_Pad_D1.5mm
U1: RT9080-33GJ5; TSOT-23-5; LCSC C841192
U2: PCF8563T; SOIC-8_3.9x4.9mm_P1.27mm; LCSC C7440
U3: TPS651851RSLR; LCSC C139292
U4: USBLC6-2P6; SOT-666; LCSC C2827693
U5: XC6206PxxxMR; SOT-23-3; LCSC C5446
U6: RY3730; SOT-23-6_RY3730_Led_PWM; LCSC C370887
U8: ESP32-S3-WROOM-1; LCSC C2913202
U9: CH340C; SOIC-16_3.9x9.9mm_P1.27mm; LCSC C84681
U10: ED060XC5; X05A20H34G; LCSC C528053
U11: TP4056; TP4056_SOP-8-PP; LCSC C16581
Y1: Crystal_Small; Q13FC1350000400-Crystal; LCSC C32346

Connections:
3.3V: C3.2, C17.1, C18.2, D12.2 (A), J3.4, J11.4 (VDD), J12.2, R4.1, R6.1, R10.2, R12.1, R14.1, R15.2, R17.1, RN1.1 (R1.1), RN1.2 (R2.1), RN1.3 (R3.1), RN1.4 (R4.1), U1.5 (VOUT), U3.45 (VIN3P3), U8.2 (3V3)
/15V: C31.2, C37.1, R29.1, TP4.1 (1_1), U3.19 (VPOS_DIS), U3.44 (VPOS), U10.33 (VPOS)
/+22V: C33.1, C34.1, D6.1 (K), R23.1, R26.1, TP1.1 (1_1), U3.35 (VDDH_DIS), U10.34 (VGG)
/-15V: C8.2, C35.1, R27.1, TP2.1 (1_1), U3.3 (VNEG), U3.9 (VNEG_DIS), U10.1 (VNEG)
/-20V: C27.2, C36.1, D3.2 (A), R19.1, R28.1, TP3.1 (1_1), U3.29 (VEE_DIS), U10.2 (VEE)
/BORDER: U10.31 (BORDER)
/CC1: J1.A5 (CC1), J4.A5 (CC1), R7.1
/CC2: J1.B5 (CC2), J4.B5 (CC2), R2.1
/CKV: U8.25 (GPIO48/SPICLK_N/SUBSPICLK_N_DIFF), U10.28 (CKV)
/D0: U8.5 (GPIO5/TOUCH5/ADC1_CH4), U10.13 (D0)
/D1: U8.6 (GPIO6/TOUCH6/ADC1_CH5), U10.14 (D1)
/D2: U8.7 (GPIO7/TOUCH7/ADC1_CH6), U10.15 (D2)
/D3: U8.8 (GPIO15/U0RTS/ADC2_CH4/XTAL_32K_P), U10.16 (D3)
/D4: U8.9 (GPIO16/U0CTS/ADC2_CH5/XTAL_32K_NH5), U10.17 (D4)
/D5: U8.10 (GPIO17/U1TXD/ADC2_CH6), U10.18 (D5)
/D6: U8.11 (GPIO18/U1RXD/ADC2_CH7/CLK_OUT3), U10.19 (D6)
/D7: U8.12 (GPIO8/TOUCH8/ADC1_CH7/SUBSPICS1), U10.20 (D7)
/EN: C15.1, Q3.3 (C), R10.1, U8.3 (EN)
/EP_MODE: U8.18 (GPIO10/TOUCH10/ADC1_CH9/FSPICS0/FSPIIO4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), U10.27 (MODE1)
/EP_OE: U8.17 (GPIO9/TOUCH9/ADC1_CH8/FSPIHD/SUBSPIHD), U10.11 (XOE)
/EP_STV: U8.26 (GPIO45), U10.29 (SPV)
/EP_VCOM: C5.2, C38.1, R30.1, TP5.1 (1_1), U3.15 (VCOM), U10.21 (VCOM)
/ESP_USB+: J4.A6 (D+), J4.B6 (D+), U8.14 (GPIO20/U1CTS/ADC2_CH9/CLK_OUT1/USB_D+)
/ESP_USB-: J4.A7 (D-), J4.B7 (D-), U8.13 (GPIO19/U1RTS/ADC2_CH8/CLK_OUT2/USB_D-)
/GPIO_1: JP1.1 (A), U8.39 (GPIO1/TOUCH1/ADC1_CH0)
/GPIO_2: J3.3, U8.38 (GPIO2/TOUCH2/ADC1_CH1)
/GPIO_14: J11.3 (CMD), RN1.5 (R4.2)
/GPIO_35: U8.28 (SPIIO6/GPIO35/FSPID/SUBSPID)
/GPIO_36: U8.29 (SPIIO7/GPIO36/FSPICLK/SUBSPICLK)
/GPIO_37: U8.30 (SPIDQS/GPIO37/FSPIQ/SUBSPIQ)
/GPIO_38: J11.5 (CLX), RN1.6 (R3.2), U8.31 (GPIO38/FSPIWP/SUBSPIWP)
/GPIO_46: J3.2, U8.16 (GPIO46)
/IO0: J11.7 (DAT0), Q4.3 (C), R15.1, RN1.7 (R2.2), U8.27 (GPIO0/BOOT)
/LEDC1_A: C44.1, D11.1 (K), J6.1, TP6.1 (1_1), U6.5 (OVP)
/LEDC1_KA: J6.6, R13.2, U6.3 (FB)
/LEDC1_PWM: U6.4 (EN), U8.23 (GPIO21)
/LEH: U8.35 (MTMS/GPIO42), U10.10 (XLE)
/SCL: J12.4, R6.2, U2.6 (SCL), U3.17 (SCL), U8.33 (MTDO/GPIO40/CLK_OUT2)
/SDA: J12.3, R4.2, U2.5 (SDA), U3.18 (SDA), U8.32 (MTCK/GPIO39/CLK_OUT3/SUBSPICS1)
/SD_CD: J11.9 (CD), RN1.8 (R1.2)
/TPS_PWRUP: U3.21 (PWRUP), U8.19 (GPIO11/TOUCH11/ADC2_CH0/FSPID/FSPIIO5/S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)
/TPS_PWR_GOOD: R12.2, U3.23 (PWR_GOOD), U8.24 (GPIO47/SPICLK_P/SUBSPICLK_P_DIFF)
/TPS_VCOM_CTRL: U3.12 (VCOM_CTRL), U8.20 (GPIO12/TOUCH12/ADC2_CH1/FSPICLK/FSPIIO6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)
/TPS_WAKEUP: U3.5 (WAKEUP), U8.22 (GPIO14/TOUCH14/ADC2_CH3/FSPIWP/FSPIDQS/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)
/TPS_nINT: R14.2, U3.2 (NINT), U8.21 (GPIO13/TOUCH13/ADC2_CH2/FSPIQ/FSPIIO7/S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)
/TP_INT: U8.15 (GPIO3/TOUCH3/ADC1_CH2)
/UART_3.3V: C14.2, C42.2, U5.2 (VO), U9.4 (V3), U9.16 (VCC)
/USB_D+: J1.A6 (D+), J1.B6 (D+), U4.3 (I/O2), U4.4 (I/O2), U9.5 (UD+)
/USB_D-: J1.A7 (D-), J1.B7 (D-), U4.1 (I/O1), U4.6 (I/O1), U9.6 (UD-)
/USB_RXD: U8.37 (U0TXD/GPIO43/CLK_OUT1), U9.3 (RXD)
/USB_TXD: U8.36 (U0RXD/GPIO44/CLK_OUT2), U9.2 (TXD)
/VNEG_IN: C1.1, C7.1, C24.1, D1.2 (A), U3.4 (VNEG_IN), U3.16 (VCOM_PWR), U3.22 (PBKG), U3.26 (VN), U3.27 (VEE_IN), U3.49 (EPAD)
/XCL: U8.4 (GPIO4/TOUCH4/ADC1_CH3), U10.8 (XCL)
/XSTL: U8.34 (MTDI/GPIO41/CLK_OUT1), U10.12 (XSTL)
/~DTR: Q4.2 (E), R1.2, U9.13 (~DTR)
/~RTS: Q3.2 (E), R11.2, U9.14 (~RTS)
EPD_VDD: C19.1, U3.46 (V3P3), U10.6 (VDD)
unnamed: D1.1 (K), L1.1, U3.25 (VN_SW)
unnamed: C20.1, D2.2 (A), D3.1 (K)
unnamed: C30.1, D2.1 (K), U3.30 (VEE_D)
unnamed: D4.2 (A), L2.2, U3.40 (VB_SW)
unnamed: C26.2, C28.2, D4.1 (K), U3.37 (VDDH_IN), U3.42 (VB), U3.43 (VPOS_IN)
unnamed: C29.2, D5.2 (A), U3.34 (VDDH_D)
unnamed: C25.1, D5.1 (K), D6.2 (A)
unnamed: D8.1 (K), R3.2
unnamed: D9.1 (K), R8.2
unnamed: D8.2 (A), D9.2 (A), D10.1 (K), U11.4 (VCC), U11.8 (CE)
unnamed: D11.2 (A), L3.2, U6.1 (LX)
unnamed: C21.1, D12.1 (K), U2.8 (VDD)
unnamed: C23.2, JP1.2 (B), R21.2, R22.1
unnamed: Q3.1 (B), R1.1
unnamed: Q4.1 (B), R11.1
unnamed: C39.2, U2.1 (OSCI), Y1.2
unnamed: C40.2, U2.2 (OSCO), Y1.1
unnamed: R17.2, TP7.1 (1_1), U2.3 (~INT)
unnamed: C4.2, U3.7 (INT_LDO)
unnamed: R18.2, TH1.1, U3.47 (TS)
unnamed: C25.2, U3.36 (VDDH_DRV)
unnamed: R23.2, R24.1, U3.33 (VDDH_FB)
unnamed: C20.2, U3.28 (VEE_DRV)
unnamed: R19.2, R20.1, U3.31 (VEE_FB)
unnamed: C11.2, U3.1 (VREF)
unnamed: R9.2, U11.2 (PROG)
unnamed: R8.1, U11.7 (~CHRG)
unnamed: R3.1, U11.6 (~STDBY)
VBAT: C16.2, C22.2, J2.1, Q1.3 (D), R21.1, U11.5 (BAT)
VIN: C2.1, C6.2, C9.1, C10.2, C12.1, C32.2, C43.2, D7.1 (K), L2.1, L3.1, Q1.2 (S), U1.1 (VIN), U1.3 (EN), U3.10 (VIN), U3.24 (VIN_P), U6.6 (IN)

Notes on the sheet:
Battery Voltage Sense
Misc.
EPD Power
PCF8563T Real time clock via I2C
Do we really need RTC_INT pin ?
QWIIC Connector (TX / RX)
ESP32 S3 Module
PROG USB
Power 3.3V
Auto-Reset
MicroSD pins:
ADDITIONAL IOs
Battery/USB Switch
USB to UART
CDC USB
EPD Connector 34pin, 8bit
PSRAM < DO < NOT < USE
FRONT LIGHT EC060XCD 6 pin
FL Power source PWM circuit
Cold
MicroSD
Battery Jack
LiPo Charging
Close to EPD connector

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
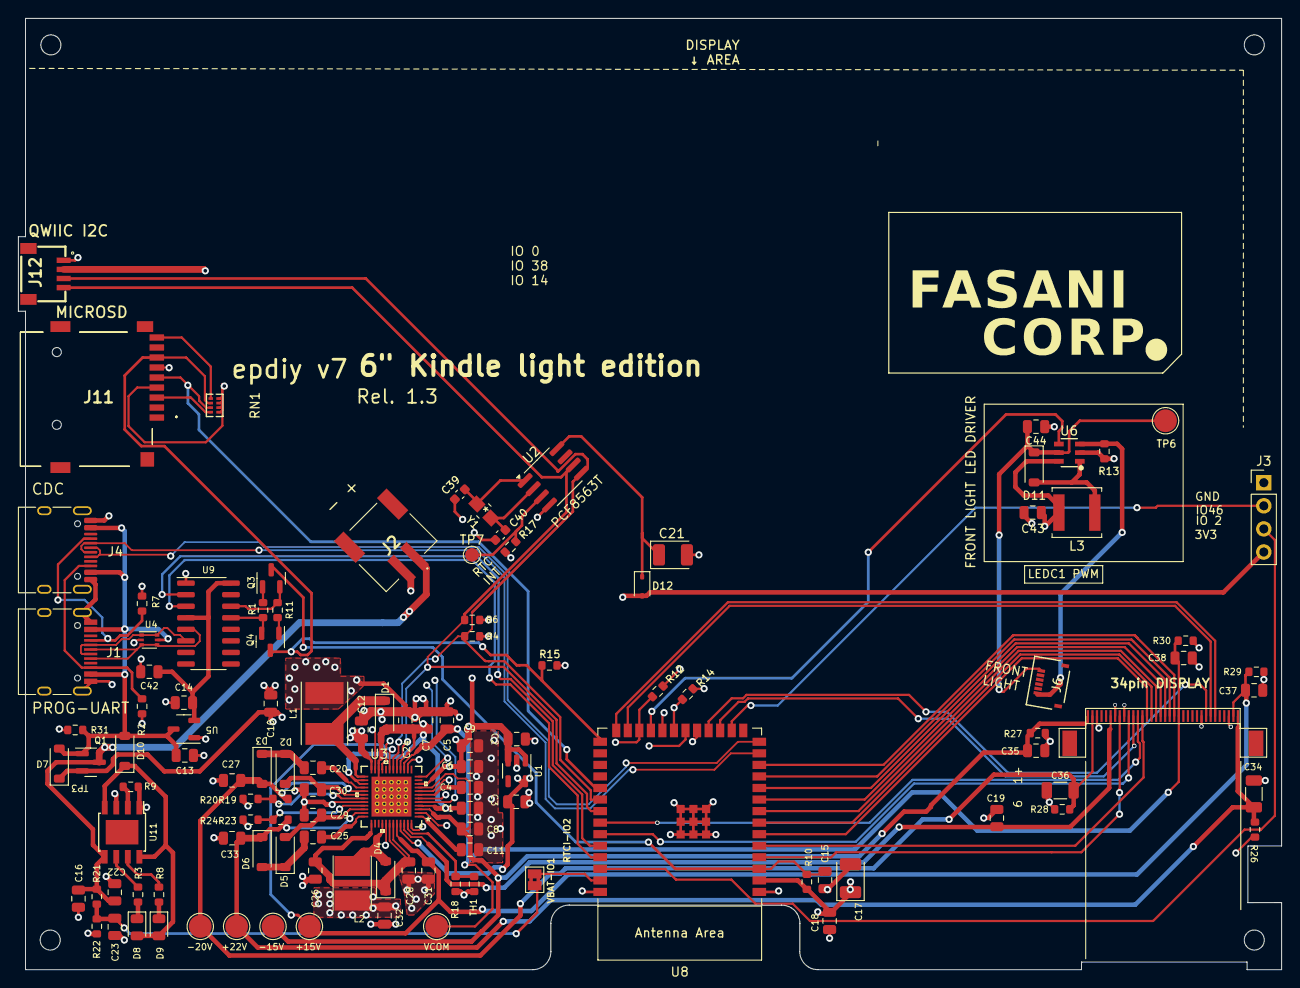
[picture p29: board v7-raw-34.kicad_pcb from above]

Board: 4 copper layers, 138.9 x 104.6 mm, 121 parts (0 on the bottom side), 84 nets.

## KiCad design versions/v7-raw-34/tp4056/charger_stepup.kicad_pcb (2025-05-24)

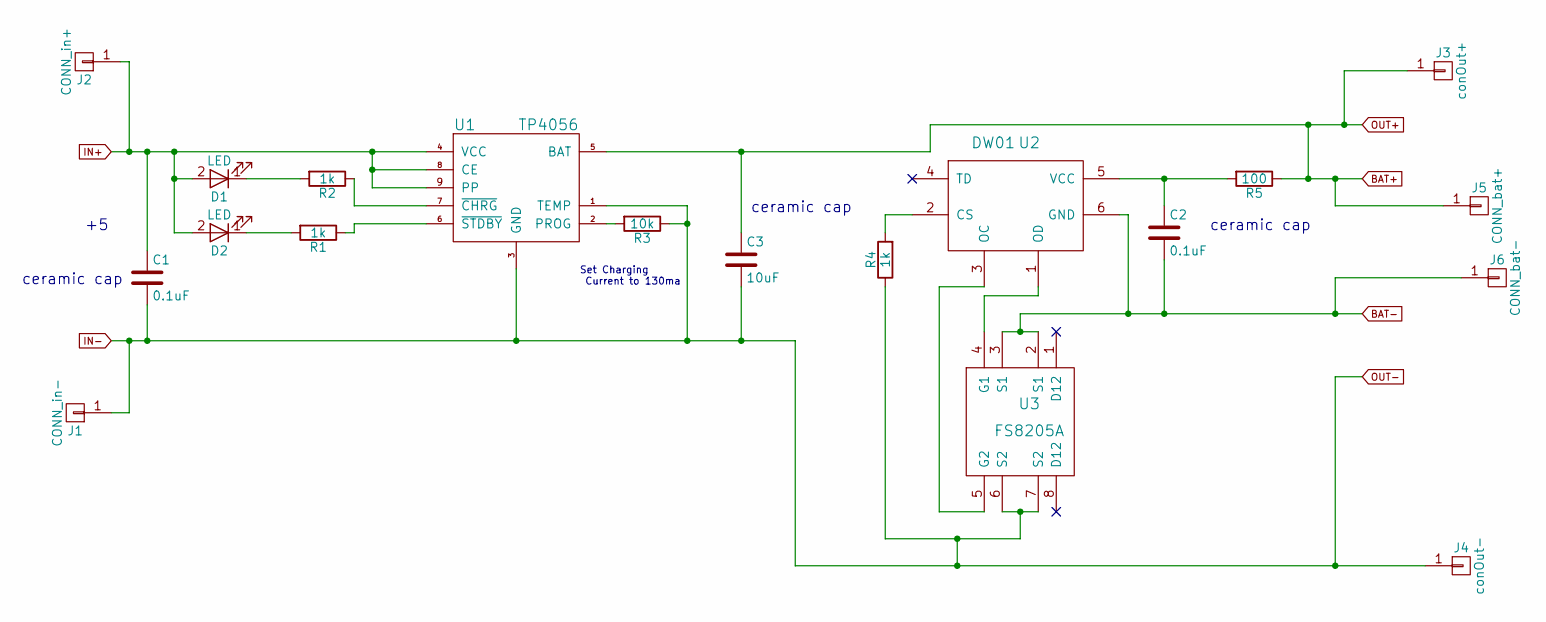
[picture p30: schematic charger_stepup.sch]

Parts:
C1, C2: 0.1uF; C_0805_HandSoldering
C3: 10uF; C_0805_HandSoldering
D1, D2: LED; LED_0603_HandSoldering
J1: CONN_in-; Pin_Header_Straight_1x01_Pitch2.54mm
J2: CONN_in+; Pin_Header_Straight_1x01_Pitch2.54mm
J3: conOut+; Pin_Header_Straight_1x01_Pitch2.54mm
J4: conOut-; Pin_Header_Straight_1x01_Pitch2.54mm
J5: CONN_bat+; Pin_Header_Straight_1x01_Pitch2.54mm
J6: CONN_bat-; Pin_Header_Straight_1x01_Pitch2.54mm
R1, R2, R4: 1k; R_0603_HandSoldering
R3: 10k; R_0603_HandSoldering
R5: 100; R_0603_HandSoldering
U1: TP4056; TP4056_SOP-8-PP
U2: DW01; SOT-23-6_Handsoldering
U3: FS8205A; TSSOP-8_4.4x3mm_Pitch0.65mm

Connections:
BAT+: C3.1, J3.1, J5.1, R5.1, U1.5 (BAT)
BAT-: C2.2, J6.1, U2.6 (GND), U3.2 (S1), U3.3 (S1)
IN+: C1.1, D1.2 (A), D2.2 (A), J2.1, U1.4 (VCC), U1.8 (CE), U1.9 (PP)
IN-: C1.2, C3.2, J1.1, J4.1, R3.1, R4.1, U1.1 (TEMP), U1.3 (GND), U3.6 (S2), U3.7 (S2)
unnamed: C2.1, R5.2, U2.5 (VCC)
unnamed: D1.1 (K), R2.2
unnamed: D2.1 (K), R1.2
unnamed: R1.1, U1.6 (~STDBY)
unnamed: R2.1, U1.7 (~CHRG)
unnamed: R3.2, U1.2 (PROG)
unnamed: R4.2, U2.2 (CS)
unnamed: U2.1 (OD), U3.4 (G1)
unnamed: U2.3 (OC), U3.5 (G2)

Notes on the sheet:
Set Charging Current to 130ma
ceramic cap

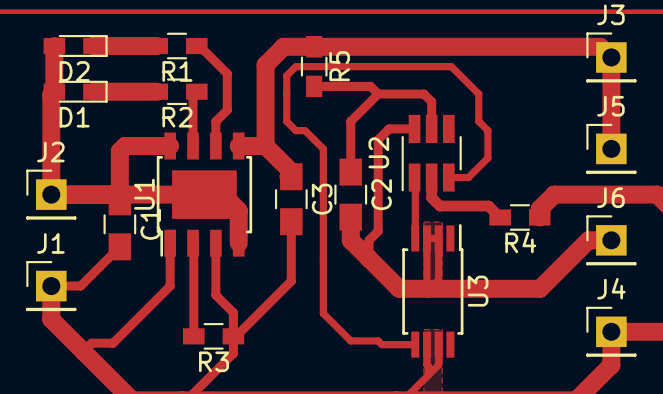
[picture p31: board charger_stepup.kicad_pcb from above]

Board: 2 copper layers, 19 parts (0 on the bottom side), 13 nets.

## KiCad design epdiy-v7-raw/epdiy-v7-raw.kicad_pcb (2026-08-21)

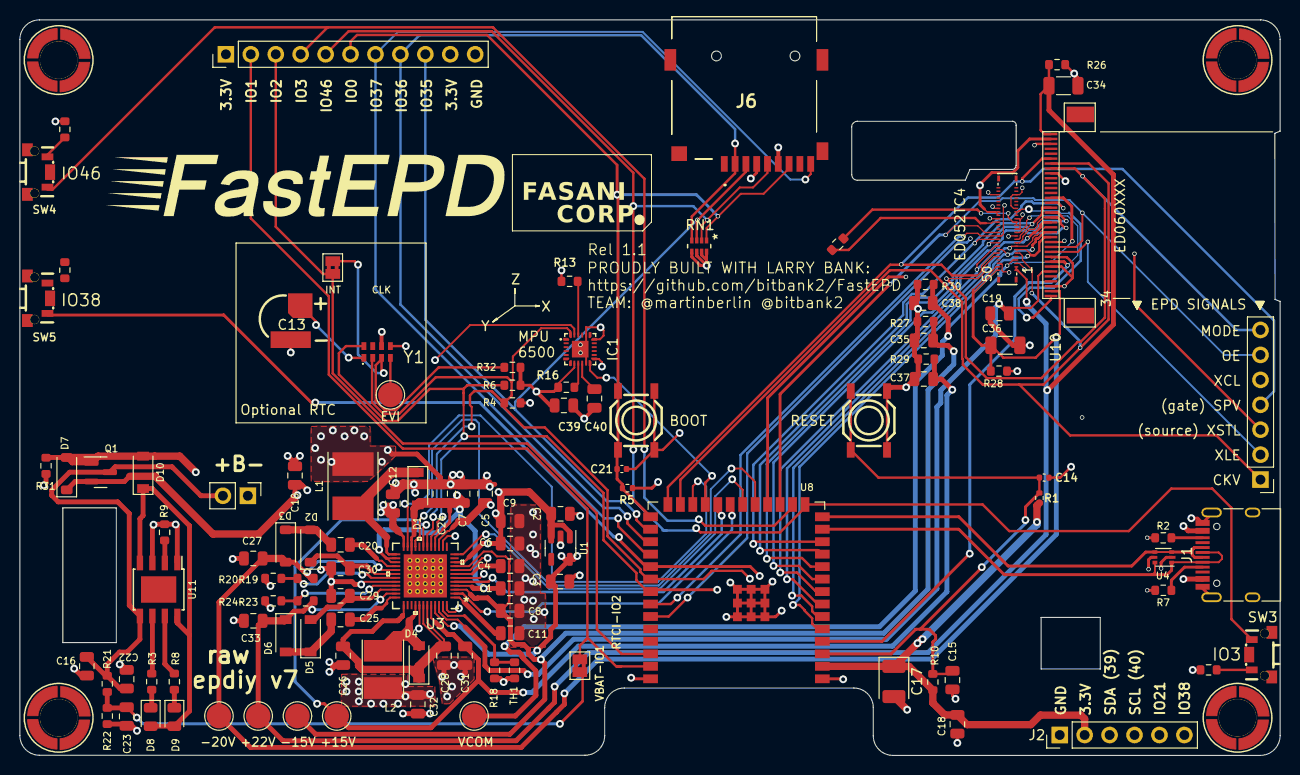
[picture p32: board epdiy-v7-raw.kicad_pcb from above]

Board: 4 copper layers, 128.4 x 74.9 mm, 117 parts (0 on the bottom side), 80 nets.

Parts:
C1, C4, C5, C7, C8, C11, C24, C26, C28, C31: 4.7uF; C_0805_2012Metric
C2, C3, C9, C12, C16, C19, C32: 10uF; C_0805_2012Metric
C6, C10: 22uF; C_0805_2012Metric
C13: superCAP; C9900013866_SUPERCAP-TH_XH414HG
C14: 1uF; C_0402_1005Metric
C15, C22, C23, C29, C30, C40: 100nF; C_0805_2012Metric
C17: 100uF; CP_EIA-3528-15_AVX-H
C18, C39: 1uF; C_0805_2012Metric
C20, C25: 10nF; C_0805_2012Metric
C21: 22pF; C_0402_1005Metric
C27, C33: 2.2uF; C_0805_2012Metric
C34, C36: 1uF/50V; C_1206_3216Metric
C35, C37, C38: 1uF/25V; C_0805_2012Metric
CN1: WP27D-S050VA3-R15000; CONN-SMD_50P-P0.35_WP27D-S050VA3
D1, D2, D3, D4, D5, D6, D7: MBR0540; D_SOD-123
D8: LED GREEN; LED_0805_2012Metric
D9: LED RED; LED_0805_2012Metric
D10: 1N5817; D_SOD-123
H1, H2, H3, H4: MountingHole; C2916320_SMTSO2015CTJ
IC1: MPU-6500; C50278_IMU_QFN-24_L3.0-W3.0-P0.40-BL-EP
J1: USB_C_Receptacle_USB2.0; USB_C_Receptacle_HRO_TYPE-C-31-M-12
J2: EXTENSION_HEADER; PinHeader_1x06_P2.54mm_Vertical
J3: SIGNALS_HEADER; PinHeader_1x07_P2.54mm_Vertical
J5: CONN_BAT; PinHeader_1x02_P2.54mm_Vertical
J6: THD2528-11SD-GF; MicroSD_THD252811SDGF
J7: ESP_HDR; PinHeader_1x11_P2.54mm_Vertical
JP1: VBAT_GPIO1; SolderJumper-2_P1.3mm_Bridged2Bar_Pad1.0x1.5mm
JP2: RTCINT_GPIO2; SolderJumper-2_P1.3mm_Bridged2Bar_Pad1.0x1.5mm
L1: 4.7uH; L_Taiyo-Yuden_NR-50xx_HandSoldering
L2: 2.2uH; L_Taiyo-Yuden_NR-40xx_HandSoldering
Q1: AO3401A; SOT-23
R1, R5: 10k; R_0402_1005Metric
R2, R4, R6, R7: 5.1k; R_0603_1608Metric
R3, R8: 2.4k; R_0603_1608Metric
R9: 3.83k; R_0603_1608Metric
R10, R13, R16, R32: 10k; R_0603_1608Metric
R11, R12, R14, R15: 10K; R_0603_1608Metric
R18: 43k; R_0603_1608Metric
R19, R23: 1M; R_0603_1608Metric
R20: 52.3k; R_0603_1608Metric
R21: 680k; R_0603_1608Metric
R22: 150k; R_0603_1608Metric
R24: 47.5k; R_0603_1608Metric
R26, R27, R28, R29: 47k; R_0603_1608Metric
R30, R31: 100k; R_0603_1608Metric
RN1: R_Pack04; RESN_F392JTCE_UNR_SD-pullup
SW1, SW2: TC-0522C-1.7-160G; C2845289_SW-SMD_4P-L5.2-W5.2-P3.70-LS6.4
SW3, SW4, SW5: K2-1806SQ-A2DW-04; C5143621_KEY-SMD_TS24ZJ
TH1: 10k/3380K; R_0603_1608Metric
TP1: +22V; TestPoint_Pad_D2.5mm
TP2: -15V; TestPoint_Pad_D2.5mm
TP3: -20V; TestPoint_Pad_D2.5mm
TP4: +15V; TestPoint_Pad_D2.5mm
TP5: VCOM; TestPoint_Pad_D2.5mm
TP6: EVI; TestPoint_Pad_D2.5mm
U1: RT9080-33GJ5; TSOT-23-5
U3: TPS651851RSLR
U4: USBLC6-2P6; SOT-666
U8: ESP32-S3-WROOM-1
U10: ED060XC5; X05A20H34G
U11: TP4056; TP4056_SOP-8-PP
Y1: RV-3032-C7; RV3032C7

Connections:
3.3V: C3.2, C17.1, C18.2, C39.2, IC1.8 (VDDIO), IC1.13 (VDD), J2.2, J6.4 (VDD), J7.1, J7.10, R1.2, R4.1, R5.2, R6.1, R10.2, R13.2, R16.2, R32.2, RN1.5 (R4.2), RN1.6 (R3.2), RN1.7 (R2.2), RN1.8 (R1.2), U1.5 (VOUT), U3.45 (VIN3P3), U8.2 (3V3), Y1.6 (VDD)
/15V: C31.2, C37.1, CN1.33, CN1.34, R29.1, TP4.1, U3.19 (VPOS_DIS), U3.44 (VPOS), U10.33 (VPOS)
/+22V: C33.1, C34.1, CN1.1, CN1.2, D6.1 (K), R23.1, R26.1, TP1.1, U3.35 (VDDH_DIS), U10.34 (VGG)
/-15V: C8.2, C35.1, CN1.17, CN1.18, R27.1, TP2.1, U3.3 (VNEG), U3.9 (VNEG_DIS), U10.1 (VNEG)
/-20V: C27.2, C36.1, CN1.49, CN1.50, D3.2 (A), R19.1, R28.1, TP3.1, U3.29 (VEE_DIS), U10.2 (VEE)
/ADD_69: IC1.9 (SDO_/_AD0), R16.1
/CKV: CN1.6, J3.1, U8.25 (GPIO48/SPICLK_N/SUBSPICLK_N_DIFF), U10.28 (CKV)
/D0: CN1.7, U8.5 (GPIO5/TOUCH5/ADC1_CH4), U10.13 (D0)
/D1: CN1.44, U8.6 (GPIO6/TOUCH6/ADC1_CH5), U10.14 (D1)
/D2: CN1.8, U8.7 (GPIO7/TOUCH7/ADC1_CH6), U10.15 (D2)
/D3: CN1.43, U8.8 (GPIO15/U0RTS/ADC2_CH4/XTAL_32K_P), U10.16 (D3)
/D4: CN1.9, U8.9 (GPIO16/U0CTS/ADC2_CH5/XTAL_32K_NH5), U10.17 (D4)
/D5: CN1.42, U8.10 (GPIO17/U1TXD/ADC2_CH6), U10.18 (D5)
/D6: CN1.10, U8.11 (GPIO18/U1RXD/ADC2_CH7/CLK_OUT3), U10.19 (D6)
/D7: CN1.41, U8.12 (GPIO8/TOUCH8/ADC1_CH7/SUBSPICS1), U10.20 (D7)
/EN: C14.2, C15.1, R1.1, R10.1, SW1.3, SW1.4, U8.3 (EN)
/EP_MODE: CN1.46, J3.7, U8.18 (GPIO10/TOUCH10/ADC1_CH9/FSPICS0/FSPIIO4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), U10.27 (MODE1)
/EP_OE: CN1.39, J3.6, U8.17 (GPIO9/TOUCH9/ADC1_CH8/FSPIHD/SUBSPIHD), U10.11 (XOE)
/EP_SPV: CN1.45, J3.4, U8.26 (GPIO45), U10.29 (SPV)
/EP_VCOM: C5.2, C38.1, CN1.4, R30.1, TP5.1, U3.15 (VCOM), U10.21 (VCOM)
/ESP_USB+: J1.A6 (D+), J1.B6 (D+), U4.3 (I/O2), U4.4 (I/O2), U8.14 (GPIO20/U1CTS/ADC2_CH9/CLK_OUT1/USB_D+)
/ESP_USB-: J1.A7 (D-), J1.B7 (D-), U4.1 (I/O1), U4.6 (I/O1), U8.13 (GPIO19/U1RTS/ADC2_CH8/CLK_OUT2/USB_D-)
/GPIO_1: J7.2, JP1.1 (A), U8.39 (GPIO1/TOUCH1/ADC1_CH0)
/GPIO_2: J7.3, JP2.2 (B), U8.38 (GPIO2/TOUCH2/ADC1_CH1)
/GPIO_3: J6.5 (CLX), J7.5, RN1.2 (R2.1), SW3.2, U8.15 (GPIO3/TOUCH3/ADC1_CH2)
/GPIO_35: J6.3 (CMD), J7.9, RN1.3 (R3.1), U8.28 (SPIIO6/GPIO35/FSPID/SUBSPID)
/GPIO_36: J6.2 (CD/DAT3), J7.8, RN1.4 (R4.1), U8.29 (SPIIO7/GPIO36/FSPICLK/SUBSPICLK)
/GPIO_37: J6.9 (CD), J7.7, U8.30 (SPIDQS/GPIO37/FSPIQ/SUBSPIQ)
/GPIO_38: J2.5, SW5.2, U8.31 (GPIO38/FSPIWP/SUBSPIWP)
/GPIO_46: J7.4, SW4.2, U8.16 (GPIO46)
/IO0: C21.1, J6.7 (DAT0), J7.6, R5.1, RN1.1 (R1.1), SW2.3, SW2.4, U8.27 (GPIO0/BOOT)
/RTC_INT: JP2.1 (A), R32.1, Y1.3 (~INT)
/SCL: IC1.23 (SCL_/_SCLK), J2.4, R6.2, U3.17 (SCL), U8.33 (MTDO/GPIO40/CLK_OUT2), Y1.8 (SCL)
/SDA: IC1.24 (SDA_/_SDI), J2.3, R4.2, U3.18 (SDA), U8.32 (MTCK/GPIO39/CLK_OUT3/SUBSPICS1), Y1.2 (SDA)
/TPS_PWRUP: U3.21 (PWRUP), U8.19 (GPIO11/TOUCH11/ADC2_CH0/FSPID/FSPIIO5/S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)
/TPS_PWR_GOOD: U3.23 (PWR_GOOD), U8.24 (GPIO47/SPICLK_P/SUBSPICLK_P_DIFF)
/TPS_VCOM_CTRL: U3.12 (VCOM_CTRL), U8.20 (GPIO12/TOUCH12/ADC2_CH1/FSPICLK/FSPIIO6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)
/TPS_WAKEUP: U3.5 (WAKEUP), U8.22 (GPIO14/TOUCH14/ADC2_CH3/FSPIWP/FSPIDQS/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)
/TPS_nINT: U3.2 (NINT), U8.21 (GPIO13/TOUCH13/ADC2_CH2/FSPIQ/FSPIIO7/S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)
/VNEG_IN: C1.1, C7.1, C24.1, D1.2 (A), U3.4 (VNEG_IN), U3.16 (VCOM_PWR), U3.22 (PBKG), U3.26 (VN), U3.27 (VEE_IN), U3.49 (EPAD)
/XCL: CN1.12, J3.5, U8.4 (GPIO4/TOUCH4/ADC1_CH3), U10.8 (XCL)
/XLE: CN1.11, J3.2, U8.35 (MTMS/GPIO42), U10.10 (XLE)
/XSTL: CN1.40, J3.3, U8.34 (MTDI/GPIO41/CLK_OUT1), U10.12 (XSTL)
BAT+: C16.2, C22.2, J5.2, Q1.3 (D), R21.1, U11.5 (BAT)
EPD_VDD: C19.1, CN1.14, CN1.15, R11.2, U3.46 (V3P3), U10.6 (VDD)
GND: C1.2, C2.2, C3.1, C4.1, C5.1, C6.1, C7.2, C8.1, C9.2, C10.1, C11.1, C12.2, C13.2, C14.1, C15.2, C16.1, C17.2, C18.1, C19.2, C21.2, C22.1, C23.1, C24.2, C26.1, C27.1, C28.1, C29.1, C30.2, C31.1, C32.1, C33.2, C34.2, C35.2, C36.2, C37.2, C38.2, C39.1, C40.2, CN1.3, CN1.13, CN1.16, CN1.19, CN1.23, CN1.28, CN1.32, CN1.35, CN1.48, IC1.11 (FSYNC), IC1.18 (GND_1), IC1.20 (RESV_2), IC1.25 (GND_2), J1.A1 (GND), J1.A12 (GND), J1.B1 (GND), J1.B12 (GND), J1.S1 (SHIELD), J2.1, J5.1, J6.6 (VSS), J7.11, L1.2, R2.2, R7.2, R9.1, R12.2, R14.2, R15.2, R18.1, R20.2, R22.2, R24.2, R26.2, R27.2, R28.2, R29.2, R30.2, R31.2, SW1.1, SW1.2, SW2.1, SW2.2, TH1.2, U1.2 (GND), U3.6 (DGND), U3.8 (AGND1), U3.14 (VCOM_DIS), U3.32 (PGND2), U3.41 (PGND1), U3.48 (AGND2), U4.2 (GND), U8.1 (GND), U8.40 (GND), U8.41 (GND), U10.3 (VSS), U10.7 (VSS), U10.9 (VSS), U10.26 (VSS), U10.32 (VSS), U11.1 (TEMP), U11.3 (GND), Y1.5 (VSS)
IMU_INT: IC1.12 (INT), J2.6, U8.23 (GPIO21)
unnamed: CN1.36, R11.1
unnamed: D1.1 (K), L1.1, U3.25 (VN_SW)
unnamed: C20.1, D2.2 (A), D3.1 (K)
unnamed: C30.1, D2.1 (K), U3.30 (VEE_D)
unnamed: D4.2 (A), L2.2, U3.40 (VB_SW)
unnamed: C26.2, C28.2, D4.1 (K), U3.37 (VDDH_IN), U3.42 (VB), U3.43 (VPOS_IN)
unnamed: C29.2, D5.2 (A), U3.34 (VDDH_D)
unnamed: C25.1, D5.1 (K), D6.2 (A)
unnamed: D8.1 (K), R3.2
unnamed: D9.1 (K), R8.2
unnamed: D8.2 (A), D9.2 (A), D10.1 (K), U11.4 (VCC), U11.8 (CE)
unnamed: IC1.22 (NCS), R13.1
unnamed: C40.1, IC1.10 (REGOUT)
unnamed: J1.A5 (CC1), R7.1
unnamed: J1.B5 (CC2), R2.1
unnamed: C23.2, JP1.2 (B), R21.2, R22.1
unnamed: R12.1, SW3.1
unnamed: R14.1, SW4.1
unnamed: R15.1, SW5.1
unnamed: C4.2, U3.7 (INT_LDO)
unnamed: R18.2, TH1.1, U3.47 (TS)
unnamed: C25.2, U3.36 (VDDH_DRV)
unnamed: R23.2, R24.1, U3.33 (VDDH_FB)
unnamed: C20.2, U3.28 (VEE_DRV)
unnamed: R19.2, R20.1, U3.31 (VEE_FB)
unnamed: C11.2, U3.1 (VREF)
unnamed: R9.2, U11.2 (PROG)
unnamed: R8.1, U11.7 (~CHRG)
unnamed: R3.1, U11.6 (~STDBY)
unnamed: TP6.1, Y1.4 (EVI)
VBUS: D7.2 (A), D10.2 (A), J1.A4 (VBUS), J1.A9 (VBUS), J1.B4 (VBUS), J1.B9 (VBUS), Q1.1 (G), R31.1, U4.5 (VBUS)
VDD_RTC: C13.1, Y1.1 (VBACKUP)
VIN: C2.1, C6.2, C9.1, C10.2, C12.1, C32.2, D7.1 (K), L2.1, Q1.2 (S), U1.1 (VIN), U1.3 (EN), U3.10 (VIN), U3.24 (VIN_P)

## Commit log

2025-05-24 Pending to remove UART + IO expander
    [ESP32-C3-MINI-1.STEP, ESP32-C3-MINI-1U.STEP, ESP32-C3-WROOM-02.STEP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]
2025-09-01 Add kindle 34 pins versions (RAW)
    [CONN-SMD_6P-P1.25_HC-1.25-6PWT.step, S2B-PH-SM4-TB_LF__SN_.stp, v7-kaleido-BOM.xlsx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]
2026-08-21 v7 raw corrections
    [epdiy-v7-raw.kicad_pcb]
2026-08-22 v7-raw 34
    [v7-raw-34-BOM.csv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]

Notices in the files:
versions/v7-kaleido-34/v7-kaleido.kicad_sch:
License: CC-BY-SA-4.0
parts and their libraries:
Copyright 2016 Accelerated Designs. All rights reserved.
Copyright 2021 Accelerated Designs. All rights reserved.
